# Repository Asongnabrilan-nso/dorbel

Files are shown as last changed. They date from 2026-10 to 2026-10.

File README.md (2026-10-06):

# Dorbel: an AI smart doorbell on the Arduino UNO Q

<p align="center">
  <a href="https://youtu.be/h4dxzuG-TlU">
    Watch the Dorbel demo video on YouTube
  </a>
  <br>
  <em>▶ Click to watch the demo video on YouTube</em>
</p>

<p align="center">
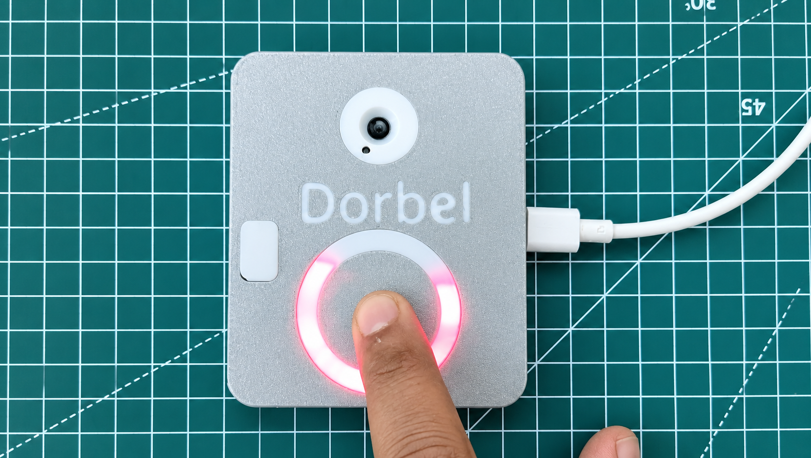
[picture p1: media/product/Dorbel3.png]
Dorbel with the light ring glowing while the button is pressed
  
</p>

Dorbel is a private video doorbell that does all of its thinking at the edge. When a visitor presses the button, the door chimes and your phone gets a Telegram photo. A dashboard on your local network shows live video and lets you talk to the visitor. An AI model running on the board also spots people at the door, even when they don't ring.

| | |
|---|---|
| **Brain** | Arduino UNO Q (4 GB), running an Arduino App Lab app |
| **Camera, mic and speaker** | Seeed XIAO ESP32S3 Sense with a MAX98357A amplifier |
| **AI** | App Lab Video Object Detection brick with the YoloX nano model |
| **Alerts** | App Lab Telegram Bot brick |
| **Privacy** | Video and audio stay on your Wi-Fi. Only the alerts leave the house. |

The build is split into nine steps. Each step ends with a check, so make sure it passes before you move on. Pin tables, the I²C protocol, subsystem tests and the full troubleshooting list live in [docs/REFERENCE.md](docs/REFERENCE.md).

## Contents

1. [How it works](#1-how-it-works)
2. [Gather the parts](#2-gather-the-parts)
3. [Print the enclosure](#3-print-the-enclosure)
4. [Flash the XIAO](#4-flash-the-xiao)
5. [Wire the UNO Q](#5-wire-the-uno-q)
6. [Create the App Lab app](#6-create-the-app-lab-app)
7. [Add AI person detection](#7-add-ai-person-detection)
8. [Add the Telegram Bot brick](#8-add-the-telegram-bot-brick)
9. [Assemble, mount and test](#9-assemble-mount-and-test)
10. [Troubleshooting](#troubleshooting)
11. [How AI was used in this project](#how-ai-was-used-in-this-project)

<br>

## 1. How it works

<p align="center">
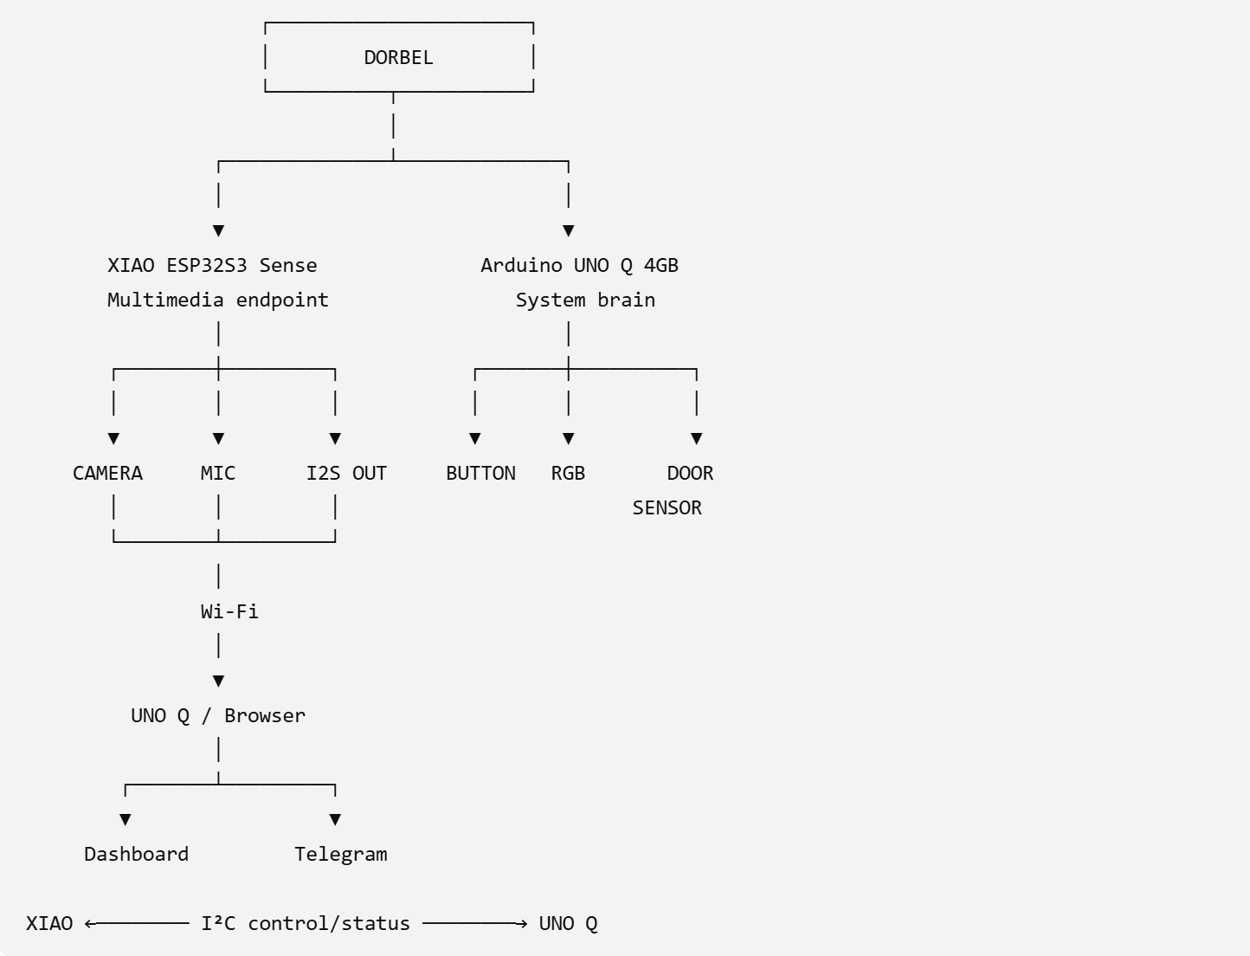
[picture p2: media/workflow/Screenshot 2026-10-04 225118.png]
Dorbel block diagram
  
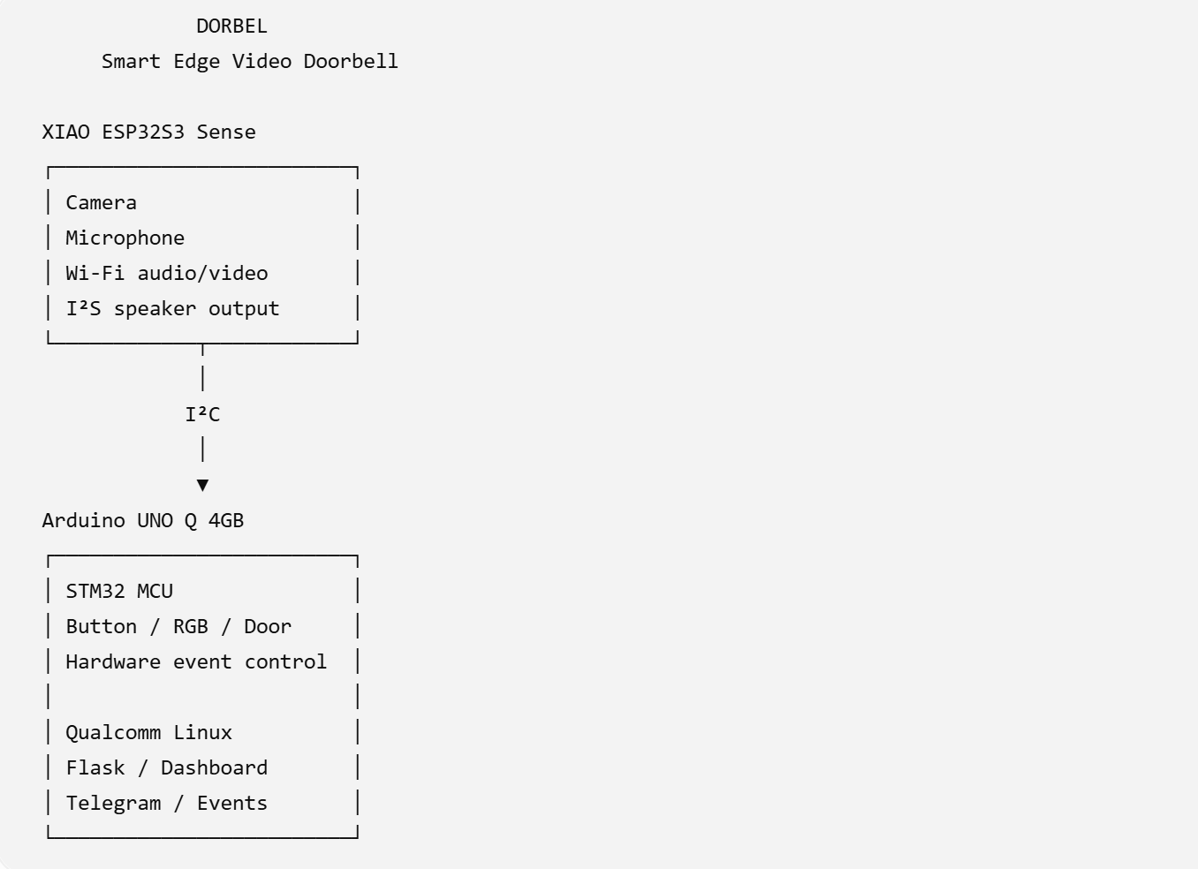
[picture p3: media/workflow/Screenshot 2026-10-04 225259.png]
What each board is responsible for
  
</p>

The UNO Q has two processors, and an App Lab app uses both of them.

| UNO Q side | What runs there | What Dorbel uses it for |
|---|---|---|
| **MCU** (STM32U585) | The app's **sketch** in `sketch/` | Button, RGB LED, I²C link to the XIAO |
| **MPU** (Qualcomm QRB2210, Debian Linux) | The app's **Python** code in `python/` and its **bricks** | Dashboard, AI, Telegram |

The two sides talk through the **Bridge**. The sketch publishes functions with `Bridge.provide_safe()` and Python calls them with `Bridge.call()`.

```
RING    button > UNO Q MCU > I²C > XIAO > chime on the door speaker
                     |
                     +> Bridge > Python > Telegram Bot brick > photo alert on your phone

VIDEO   XIAO camera > Wi-Fi > CameraHub (Python) +> dashboard (any number of viewers)
                                                 +> Video Object Detection brick (YoloX nano)
                                                       +> "person" > dashboard + phone alert

AUDIO   browser mic <> UNO Q dashboard <> Wi-Fi <> XIAO mic and speaker (push to talk)
```

One rule keeps the design simple: **I²C carries control and status, Wi-Fi carries video and audio.** The XIAO also reports its IP address over I²C, so the UNO Q finds the camera without any setup.

<br>

## 2. Gather the parts

<p align="center">
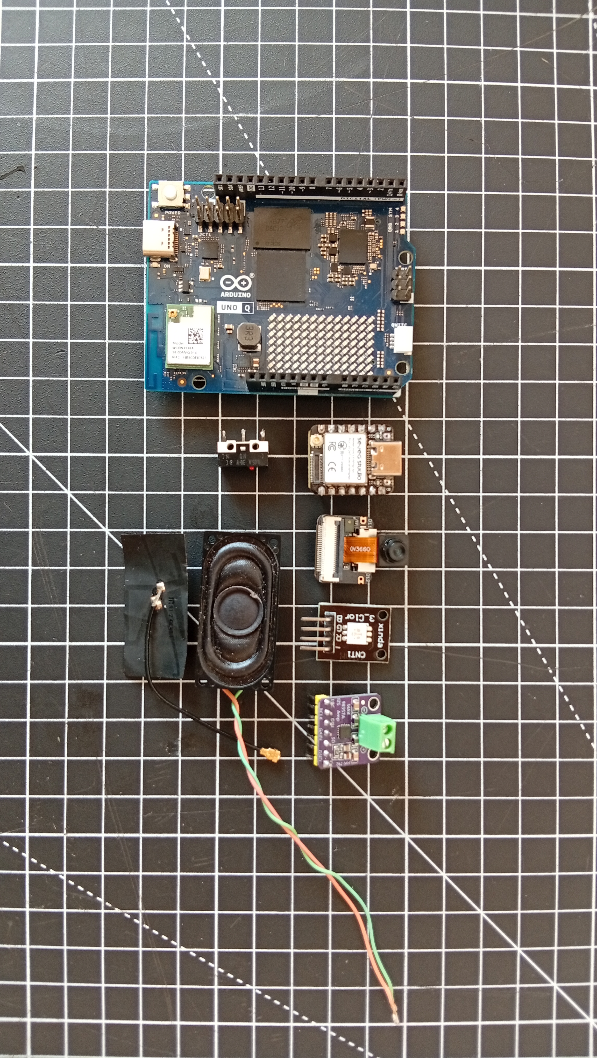
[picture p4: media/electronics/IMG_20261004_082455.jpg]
All Dorbel electronics laid out
  
</p>

| Qty | Part | Role |
|:---:|---|---|
| 1 | Arduino UNO Q (4 GB) | System brain, runs the App Lab app |
| 1 | Seeed XIAO ESP32S3 **Sense** with the camera and mic board | Camera, microphone, Wi-Fi media |
| 1 | MAX98357A I2S amplifier | Drives the speaker |
| 1 | 8 Ω, 2 W speaker | Chime and the homeowner's voice |
| 1 | Momentary push button | The doorbell |
| 1 | RGB LED (common cathode) with 3 × 220 Ω resistors, or an RGB module | Status light |
| 2 | 4.7 kΩ resistors | I²C pull-ups |
| | Jumper wires, 2 USB-C data cables, PLA filament | |
| | 2.4 GHz Wi-Fi with internet, a phone with Telegram | |

<p align="center">
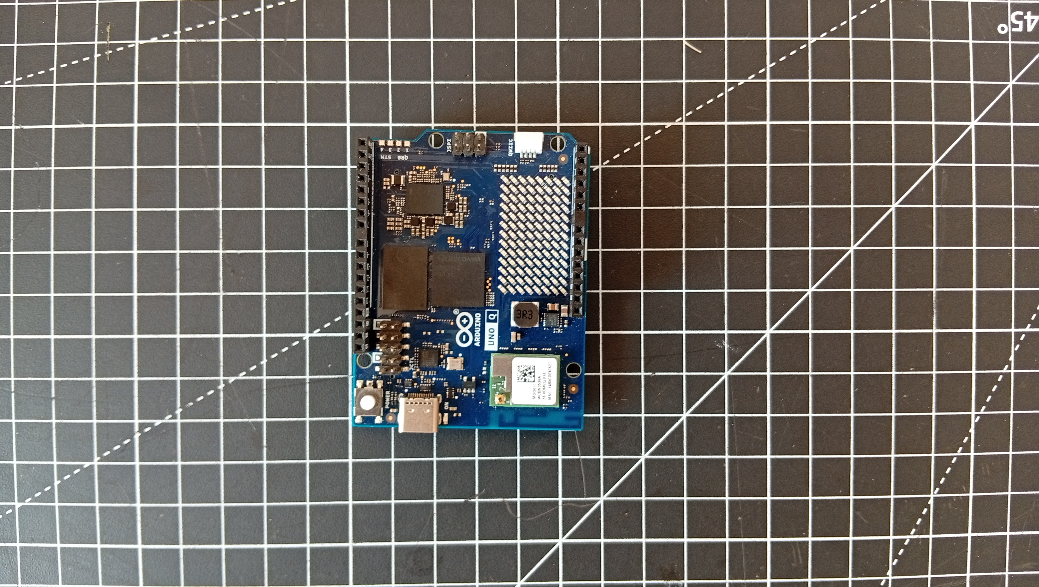
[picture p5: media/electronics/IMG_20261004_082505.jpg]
Arduino UNO Q
  
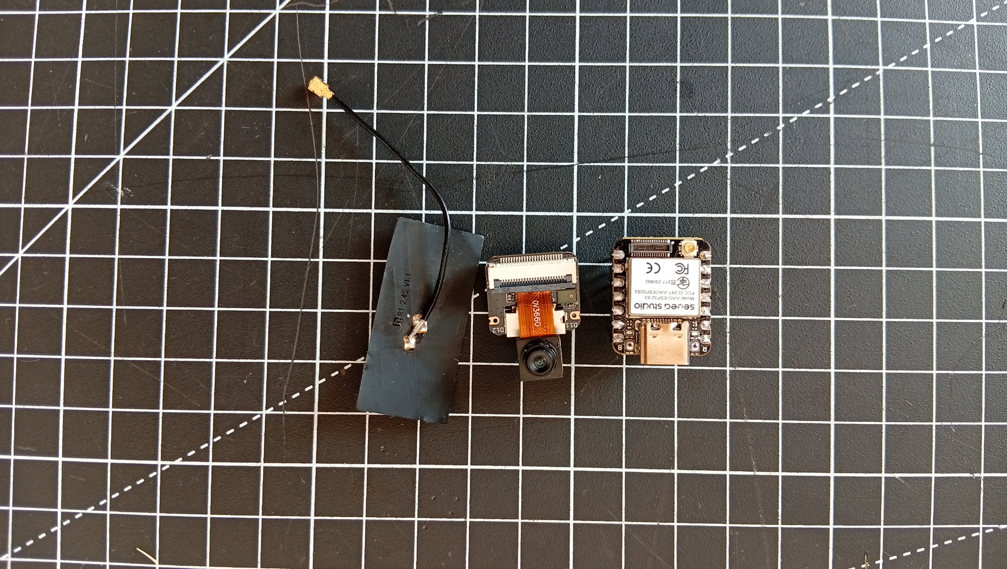
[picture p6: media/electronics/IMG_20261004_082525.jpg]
XIAO ESP32S3 Sense with camera and antenna
  
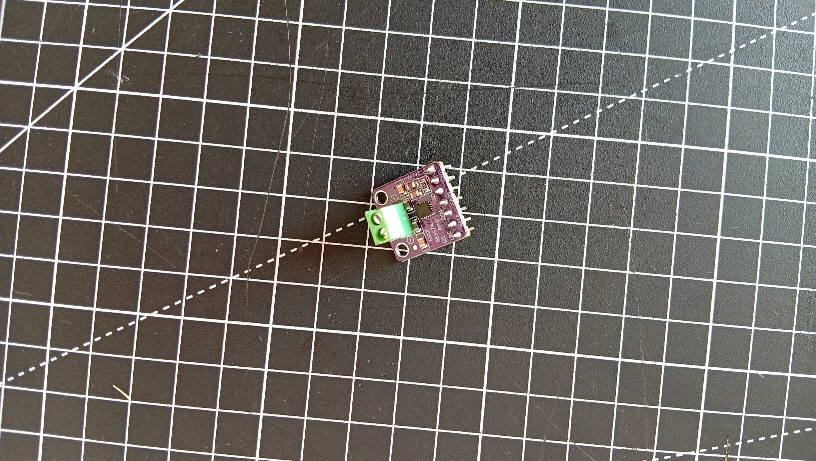
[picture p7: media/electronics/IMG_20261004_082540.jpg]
MAX98357A amplifier
  
</p>
<p align="center">
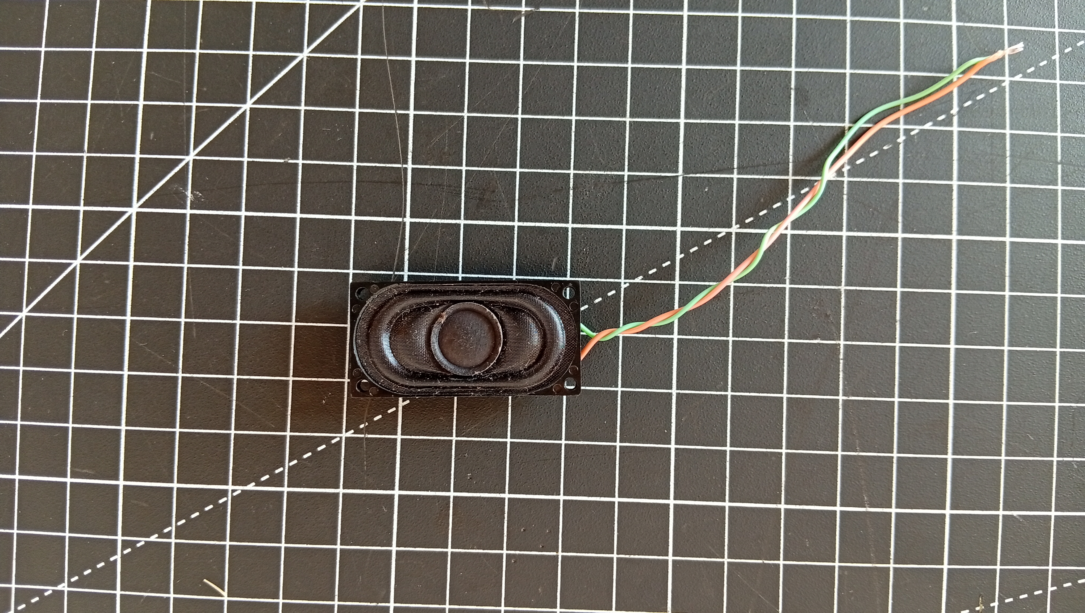
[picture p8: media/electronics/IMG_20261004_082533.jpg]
8 ohm speaker
  
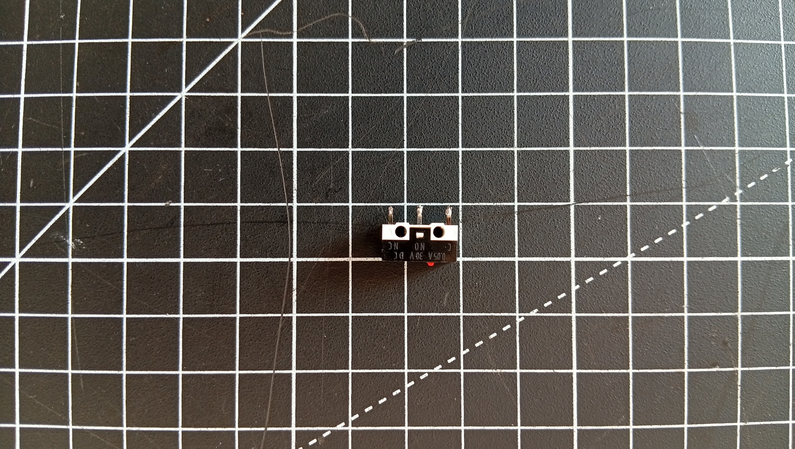
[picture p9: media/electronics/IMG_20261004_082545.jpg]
Push button
  
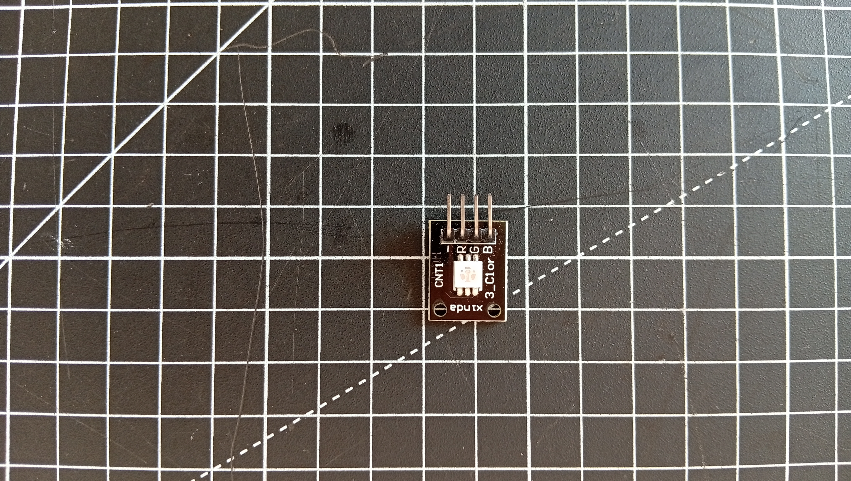
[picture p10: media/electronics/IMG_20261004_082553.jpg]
RGB LED module
  
</p>
<p align="center"><sub>UNO Q · XIAO ESP32S3 Sense · MAX98357A · speaker · push button · RGB LED</sub></p>

**Software you need:** [Arduino App Lab](https://www.arduino.cc/en/software/) (already on the UNO Q), [PlatformIO](https://platformio.org/) on your PC for the XIAO, and Telegram on your phone.

<br>

## 3. Print the enclosure

<p align="center">
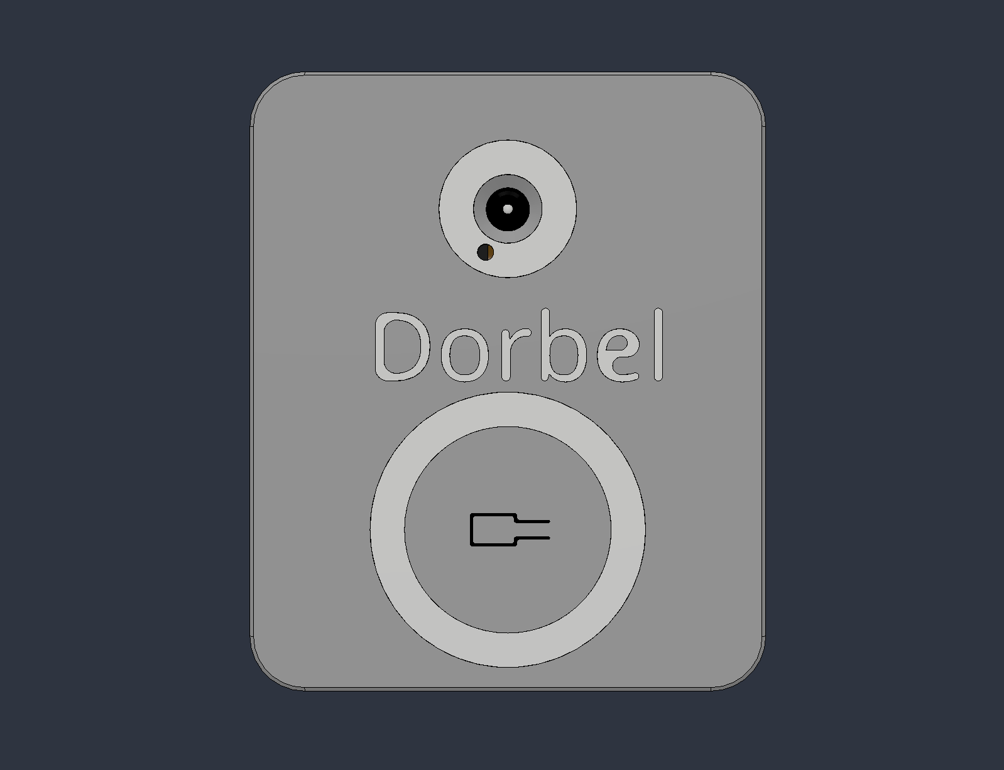
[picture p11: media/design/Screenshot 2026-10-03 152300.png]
Enclosure design in CAD
  
</p>

Print the four parts in the `stl/` folder.

| File | Part |
|---|---|
| `stl/Dorbel-Cover.3mf` | Front cover with the camera hole, light ring button and logo |
| `stl/Dorbel-Base.3mf` | Back shell that holds the electronics |
| `stl/Body2.stl` | Body |
| `stl/wall mount.stl` | Wall plate the doorbell slides onto |

<p align="center">
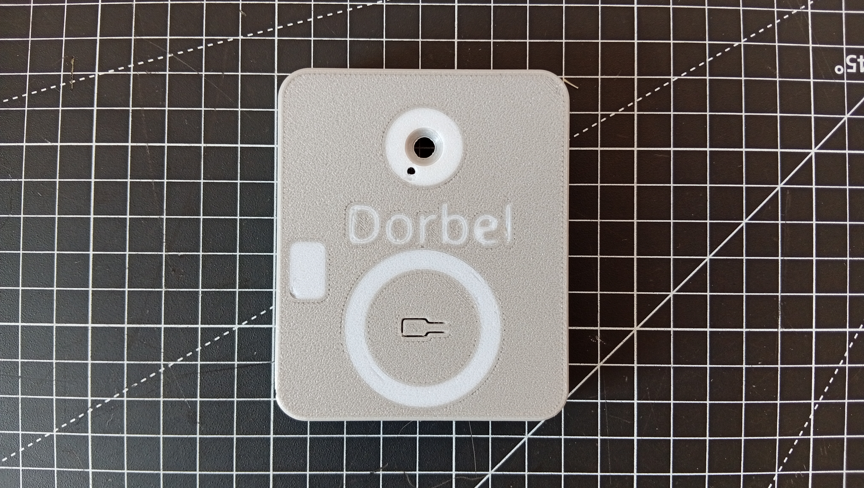
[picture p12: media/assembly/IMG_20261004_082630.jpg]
Printed front cover
  
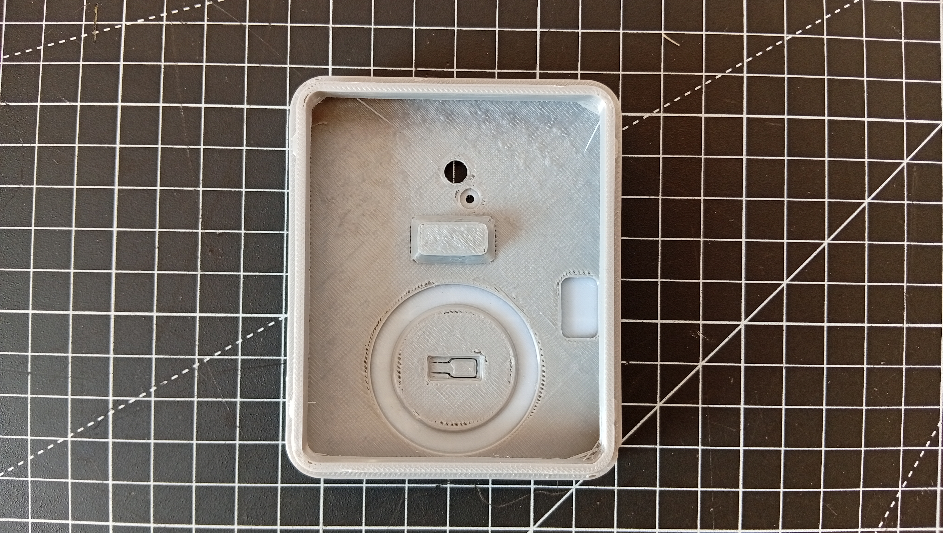
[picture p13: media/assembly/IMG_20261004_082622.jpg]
Inside of the front cover
  
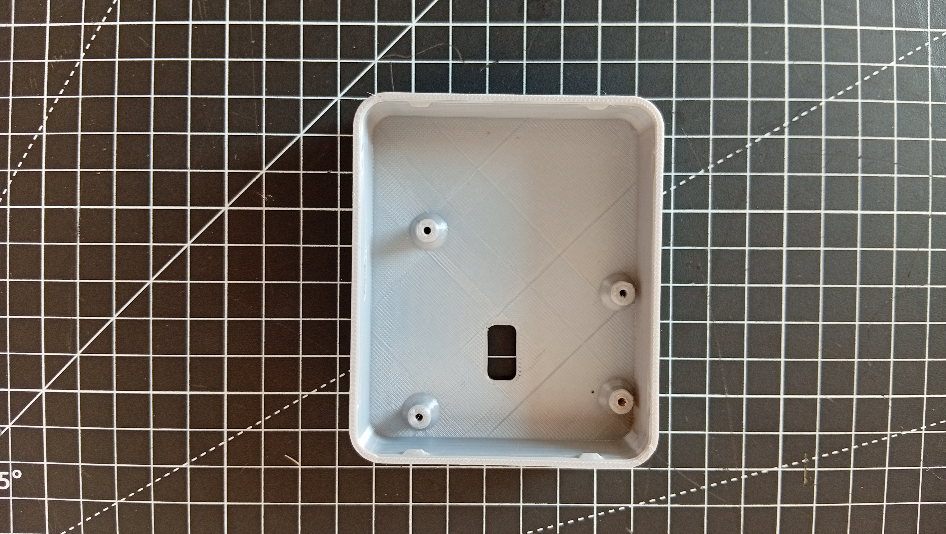
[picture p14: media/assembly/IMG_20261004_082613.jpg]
Inside of the base
  
</p>

> **✅ Check:** the button moves freely inside the ring and the camera lens lines up with the front hole.

<br>

## 4. Flash the XIAO

The XIAO firmware is a PlatformIO project in `xiao/`. Open that folder in PlatformIO, not the repository root.

### 4.1 Wire the speaker

| XIAO pin | MAX98357A pin |
|---|---|
| D8 (GPIO7) | BCLK |
| D3 (GPIO4) | LRC |
| D1 (GPIO2) | DIN |
| 5V | VIN |
| GND | GND |

Connect the speaker between **SPK+ and SPK-**. Never connect SPK- to ground.

### 4.2 Add your Wi-Fi and flash

```bash
cd xiao
cp include/secrets.example.h include/secrets.h   # add your 2.4 GHz SSID and password
pio run -t upload
pio device monitor                               # 115200 baud
```

<p align="center">
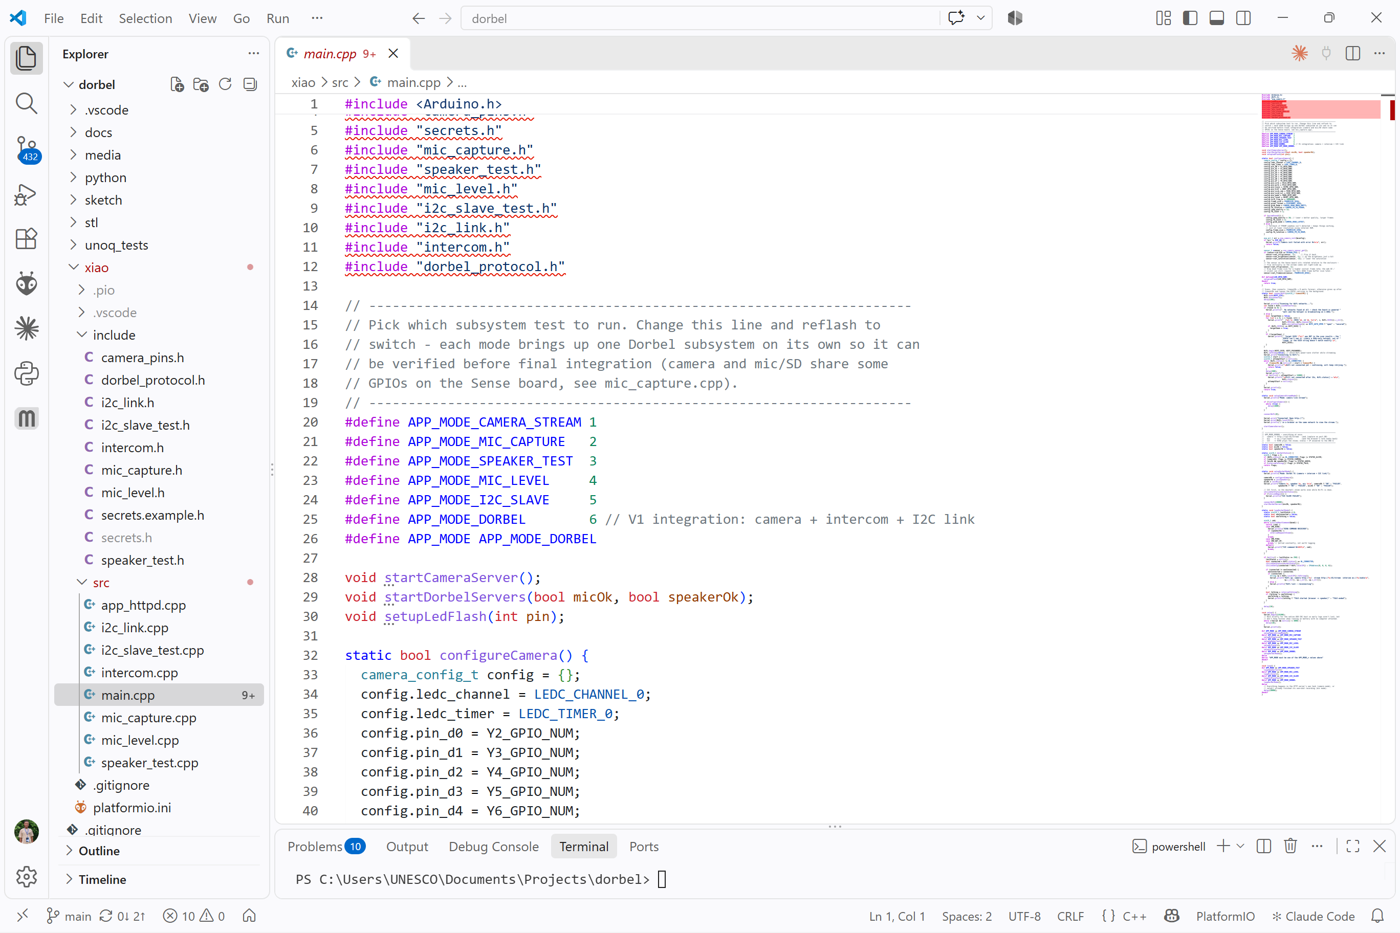
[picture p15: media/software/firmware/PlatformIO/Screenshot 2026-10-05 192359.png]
The xiao project open in VS Code with PlatformIO, showing the APP_MODE options
  
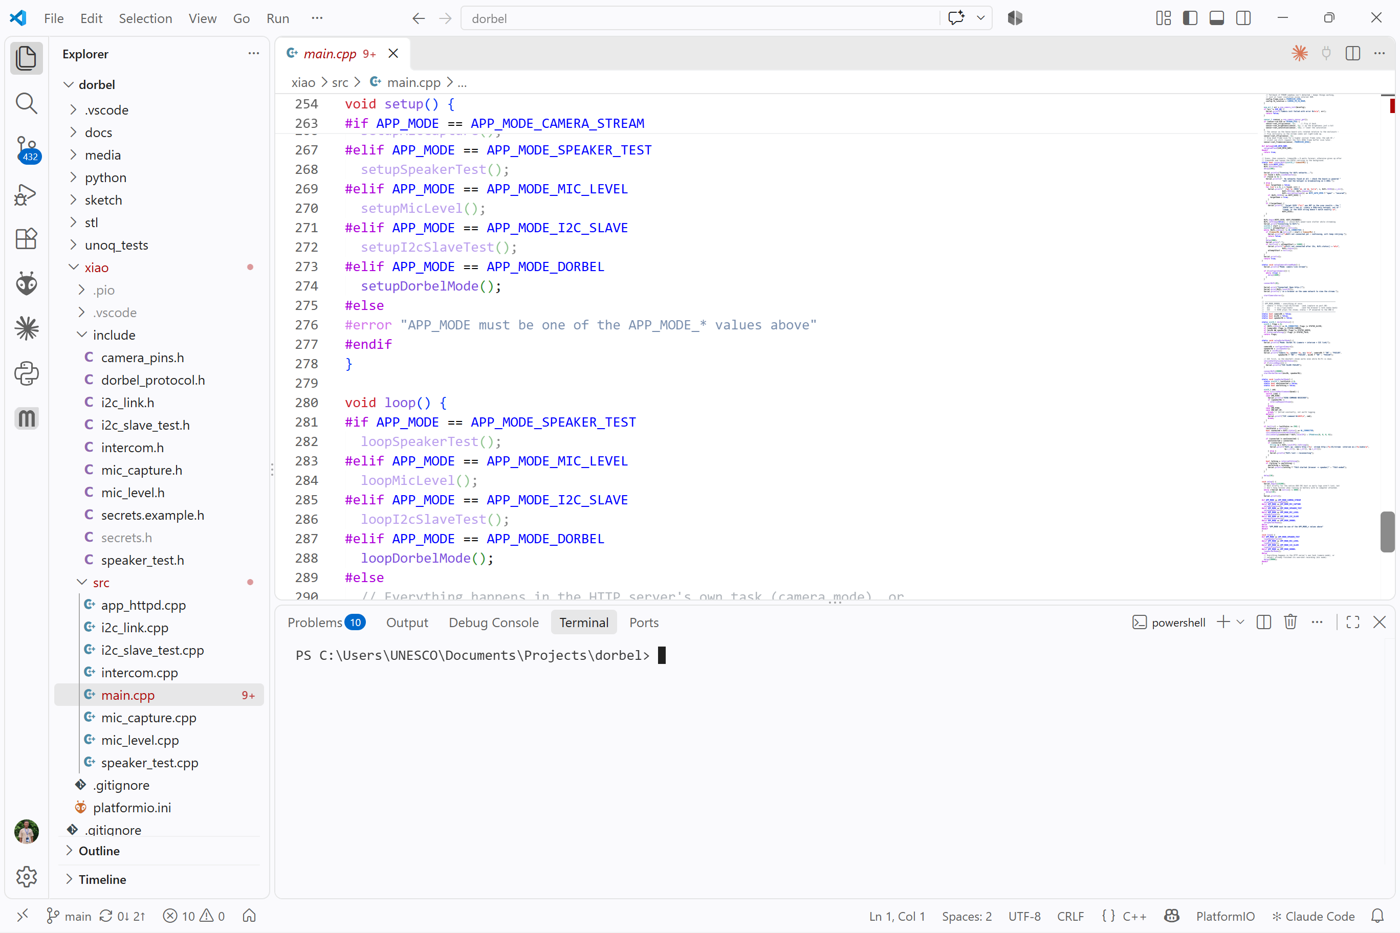
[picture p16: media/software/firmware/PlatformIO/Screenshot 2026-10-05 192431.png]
setup() and loop() picking the code for the selected APP_MODE
  
</p>
<p align="center"><sub>The <code>xiao</code> project in VS Code with PlatformIO. <code>APP_MODE</code> picks what the XIAO runs.</sub></p>

Make sure `xiao/src/main.cpp` has `#define APP_MODE APP_MODE_DORBEL`, which is the default. The other `APP_MODE_*` values test one part at a time (speaker, mic, camera, I²C) and are described in the [reference](docs/REFERENCE.md#build-order-and-test-status).

<p align="center">
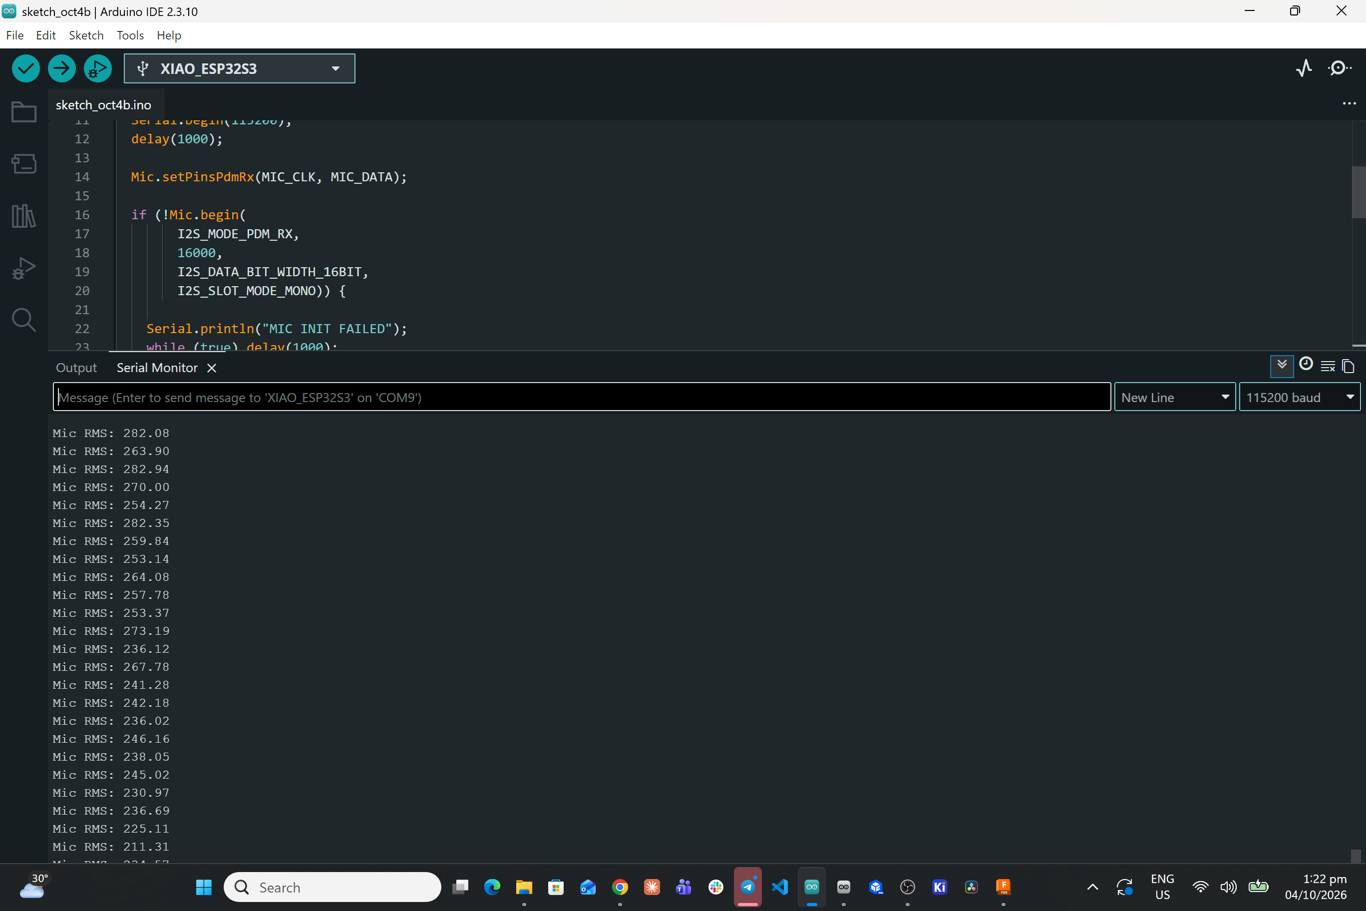
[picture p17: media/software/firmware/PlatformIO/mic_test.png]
PlatformIO serial monitor during the mic test
  
</p>
<p align="center"><sub>The mic level test, one of the single subsystem modes</sub></p>

> **✅ Check:** the serial log ends with a line like
> `WiFi up: camera http://192.168.x.y/  stream http://192.168.x.y:81/stream  intercom ws://192.168.x.y/audio`.
> Open `http://192.168.x.y/` on your PC to see the camera, then close the tab. The XIAO only streams to one client, and that slot belongs to the UNO Q.

<p align="center">
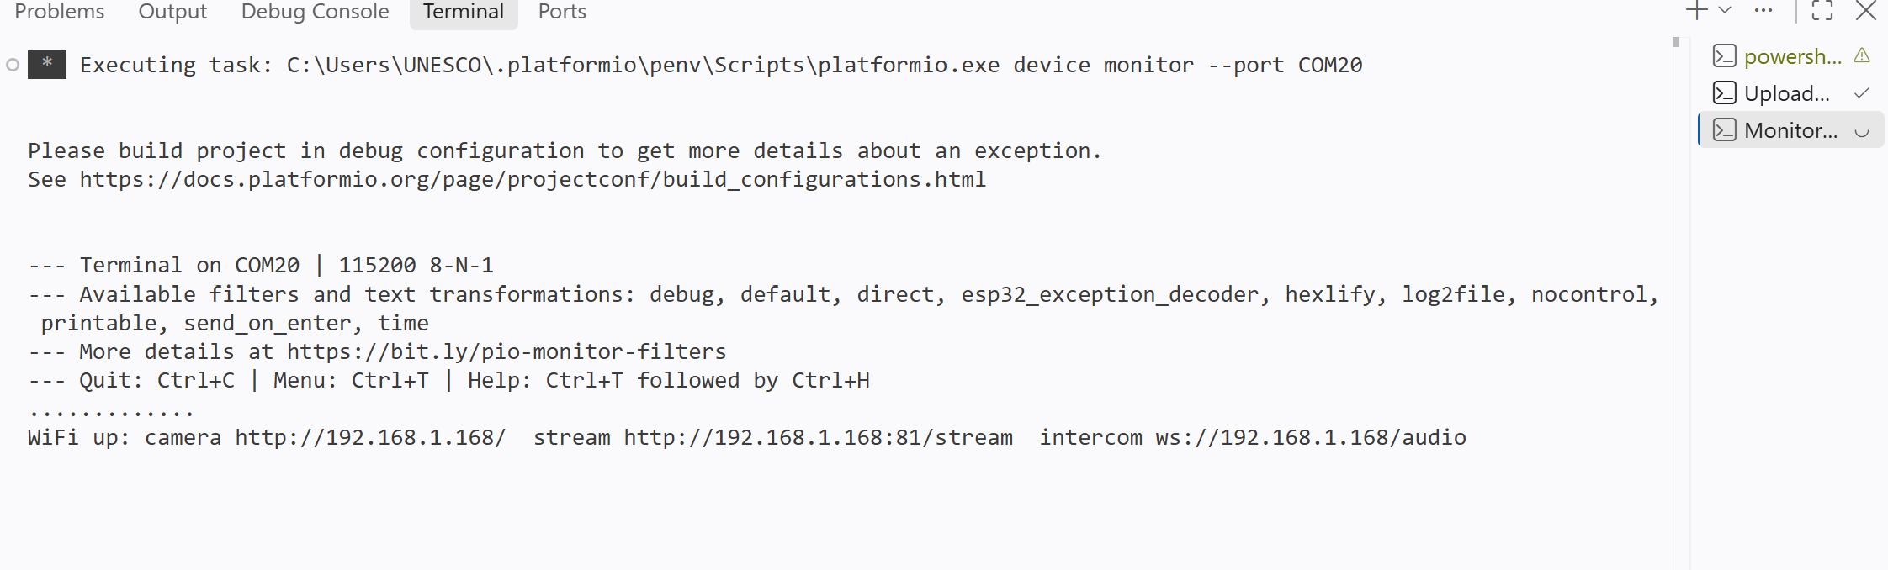
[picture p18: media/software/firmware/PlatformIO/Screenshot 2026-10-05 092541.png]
Serial monitor showing the XIAO connected to Wi-Fi with its camera, stream and intercom addresses
  
</p>

> **⚠️ Important:** the XIAO and the UNO Q must be on the **same 2.4 GHz network**. If they aren't, video, talk and photos all stop working.

<br>

## 5. Wire the UNO Q

| UNO Q pin | Connects to | Notes |
|---|---|---|
| D2 | Push button, other leg to GND | Uses `INPUT_PULLUP` |
| D3, D5, D6 | RGB red, green, blue through 220 Ω | Common cathode to GND |
| **A4** (SDA) | XIAO D4 | `Wire2` in the sketch, not the D20/D21 header |
| **A5** (SCL) | XIAO D5 | |
| GND | XIAO GND | The boards must share ground |
| 3.3 V | 4.7 kΩ to SDA and 4.7 kΩ to SCL | One pair of pull-ups for the whole bus |

The UNO Q is the I²C master and the XIAO is a slave at address `0x08`.

<p align="center">
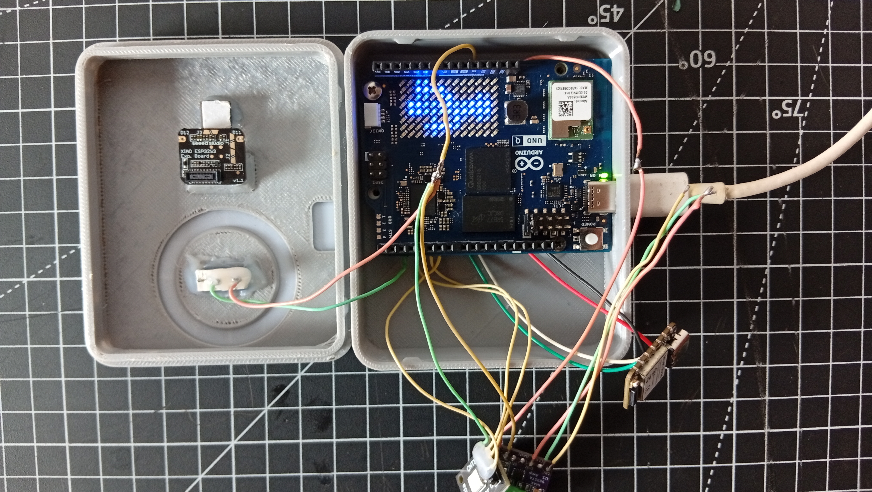
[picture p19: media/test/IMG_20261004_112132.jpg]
UNO Q and XIAO wired on the bench
  
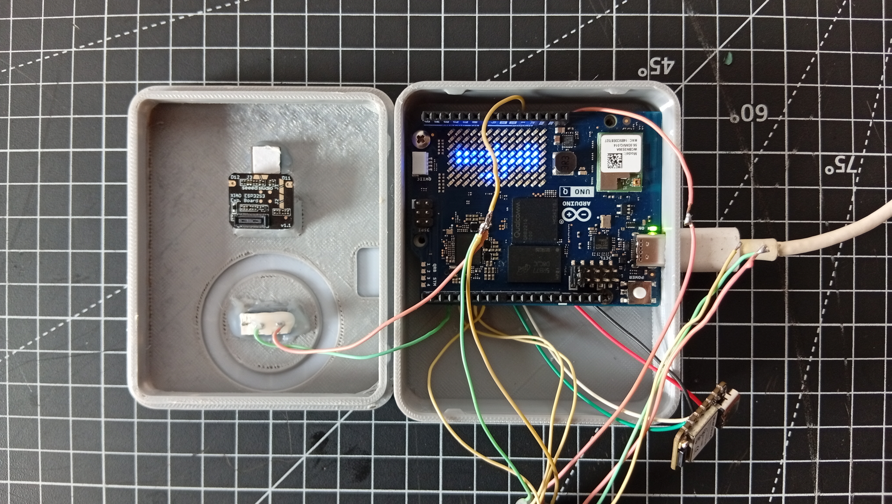
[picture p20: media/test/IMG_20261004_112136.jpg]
Bench wiring from another angle
  
</p>

> **✅ Check:** once the app runs in step 6, the RGB LED shows the link state.

<p align="center">
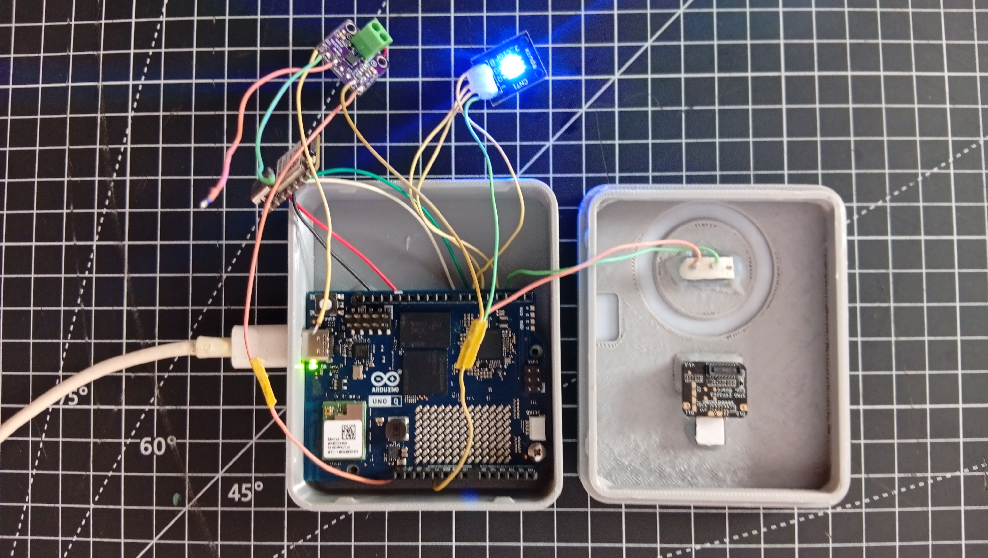
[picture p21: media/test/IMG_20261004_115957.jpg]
Blue LED: XIAO not answering
  
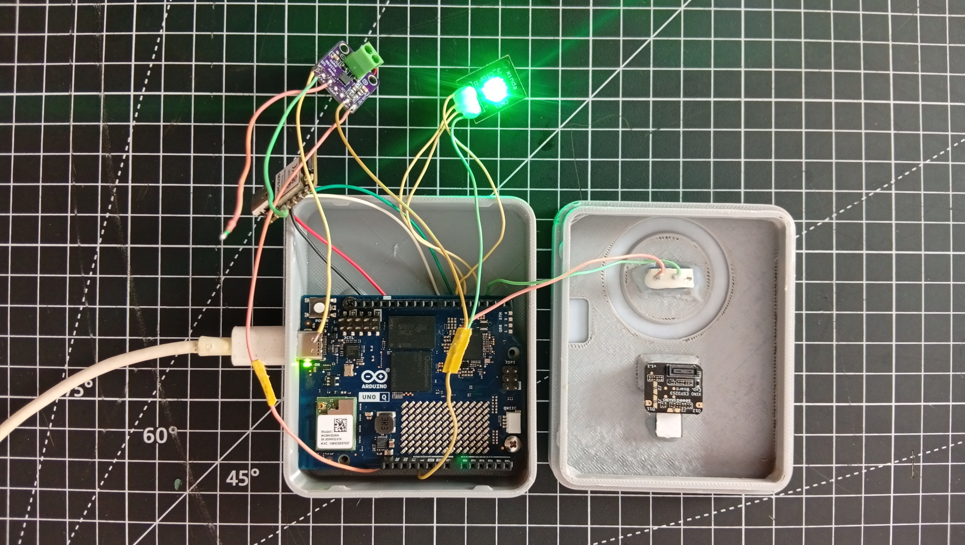
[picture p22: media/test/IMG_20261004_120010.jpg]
Green LED: idle and linked
  
</p>
<p align="center"><sub>Blue means the XIAO is not answering on I²C · Green means idle and linked · Red means a ring was just sent</sub></p>

<br>

## 6. Create the App Lab app

In App Lab, an **app** is a folder inside `~/ArduinoApps/` with this layout:

```
app.yaml      name, icon, published ports and the bricks the app uses
sketch/       code for the MCU
python/       code for Linux, starting from main.py
```

Open App Lab on your PC. If it says **No boards found**, connect the UNO Q over USB or put it on the same network as your PC. Once the board shows up, App Lab opens on its **Apps** page, with **Examples** and **Inspirations** under *Learn and Explore* if you want to see how other apps are built.

<p align="center">
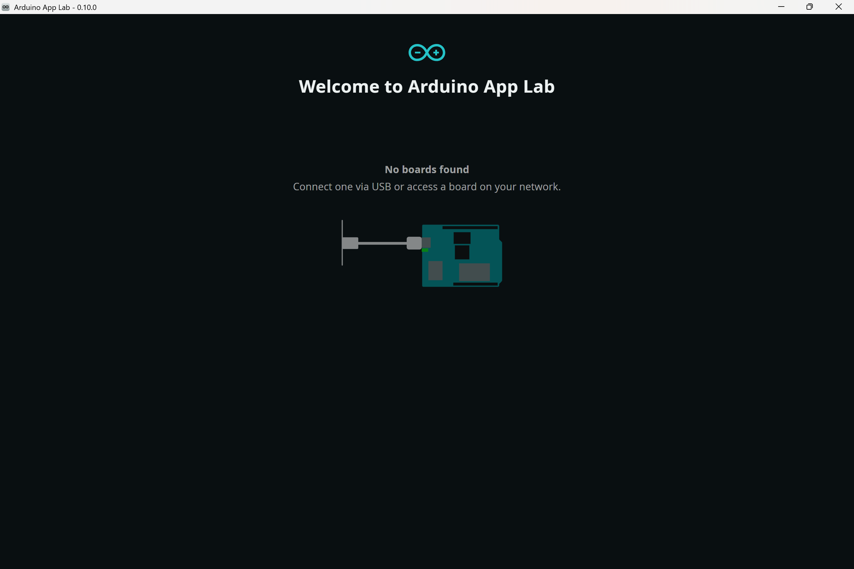
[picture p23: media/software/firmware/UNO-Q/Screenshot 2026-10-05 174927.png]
App Lab start screen waiting for a board
  
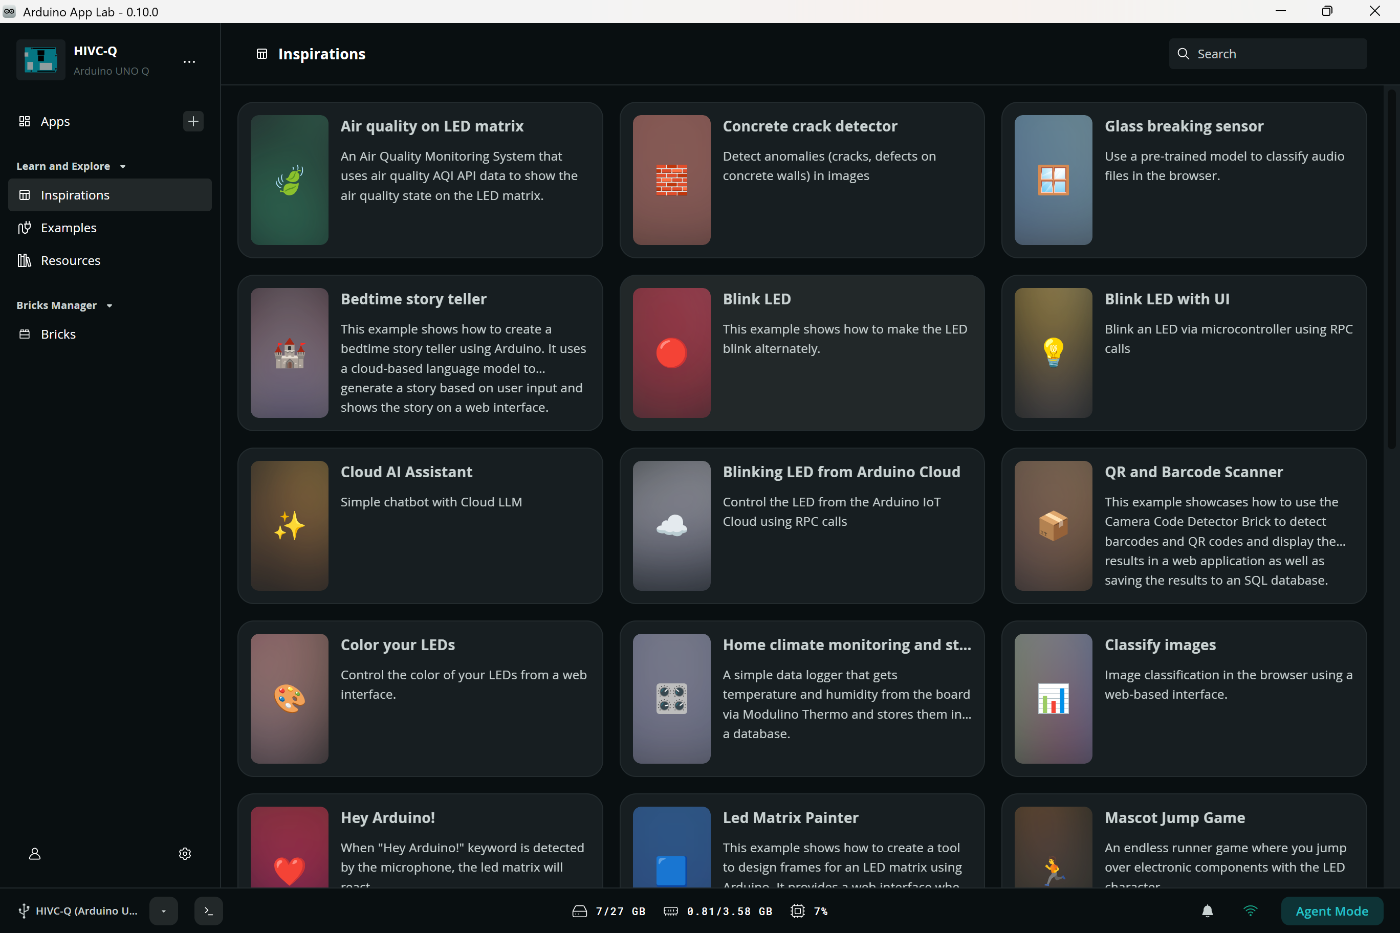
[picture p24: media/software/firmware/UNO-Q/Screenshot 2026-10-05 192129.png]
App Lab Inspirations page with example apps
  
</p>

This repository is that folder. Open a terminal on the UNO Q (the board's desktop, `ssh arduino@<board>.local` or `adb shell`) and run:

```bash
cd ~/ArduinoApps
git clone https://github.com/Asongnabrilan-nso/dorbel.git dorbel
cd dorbel/python
cp dorbel_config_example.py dorbel_config.py      # local settings, kept out of git
hostname -I                                       # shows the UNO Q's IP address
```

In `python/dorbel_config.py`, set the dashboard address that the alerts will link to:

```python
DASHBOARD_URL = "https://192.168.x.z:8443/"      # the UNO Q IP from hostname -I
```

Go back to App Lab. **Dorbel 🔔** now shows on the **Apps** page. Open it to see the bricks, the files and the code, then click **Run**.

<p align="center">
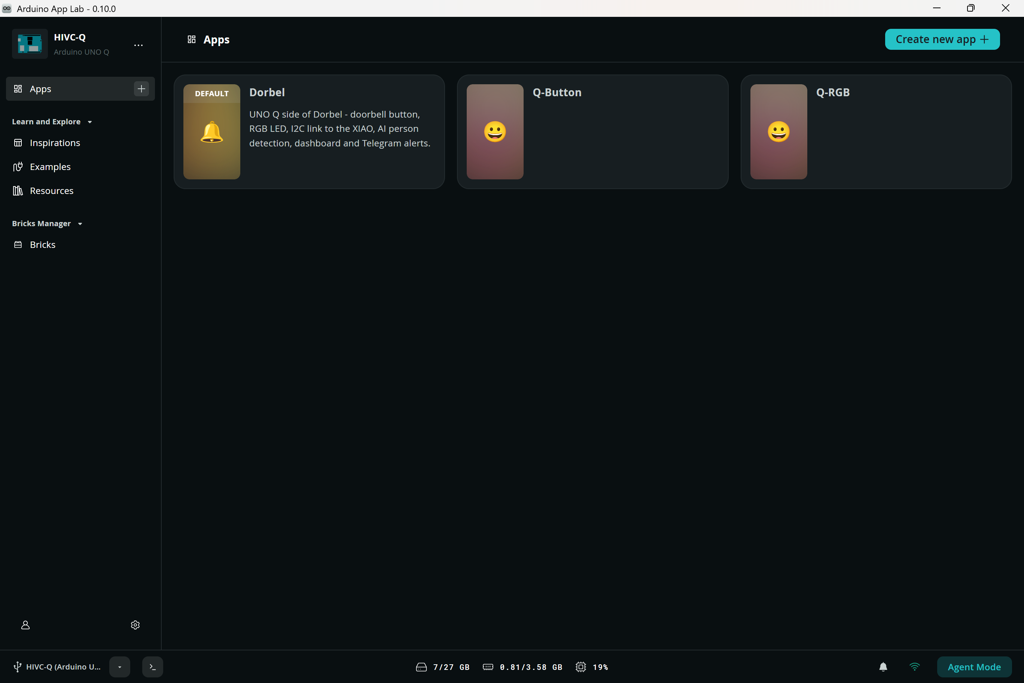
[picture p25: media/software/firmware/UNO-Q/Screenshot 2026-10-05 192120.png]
App Lab Apps page with the Dorbel app
  
</p>

When you click **Run**, App Lab will:

1. compile the sketch and flash it to the MCU (progress shows in the **App launch** tab),
2. start the app's bricks,
3. start `python/main.py` and show its output in the **Python** tab.

<p align="center">
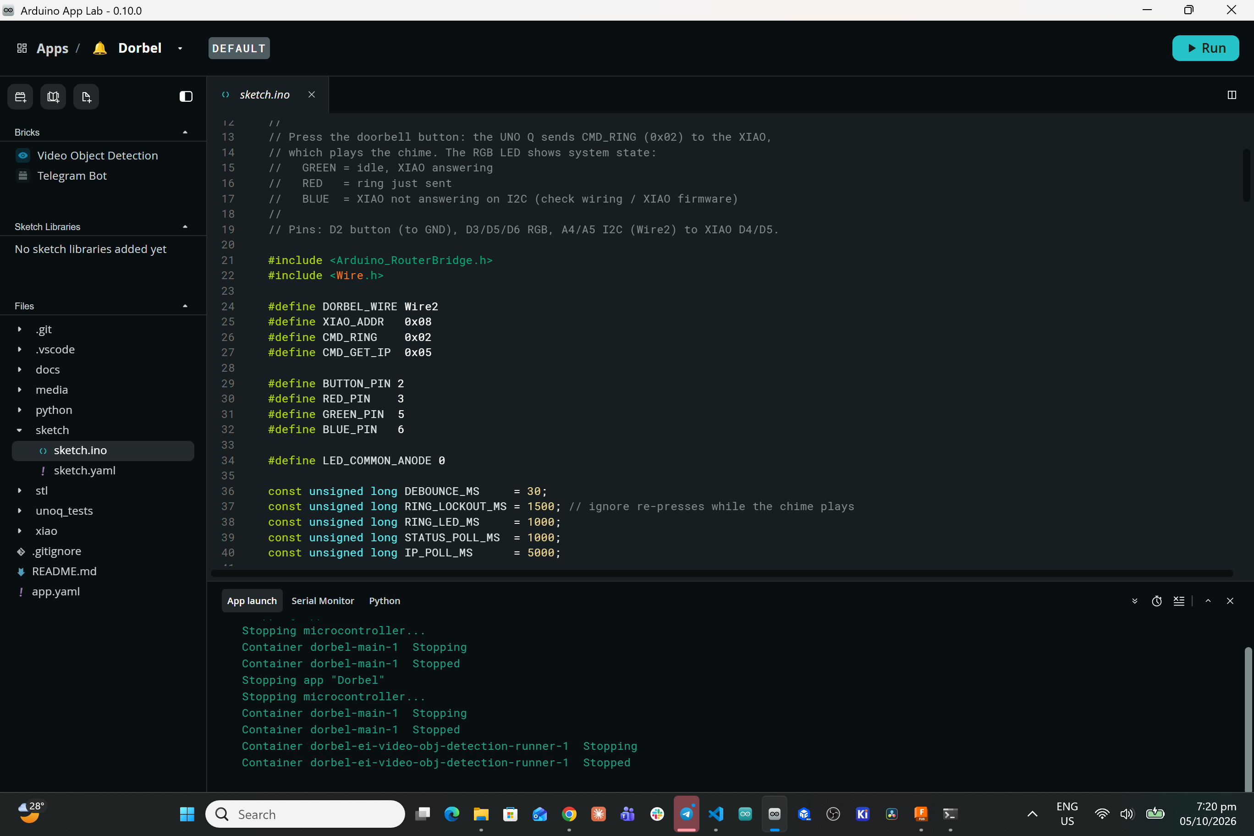
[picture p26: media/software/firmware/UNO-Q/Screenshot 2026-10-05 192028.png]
Dorbel sketch open in App Lab with the bricks listed
  
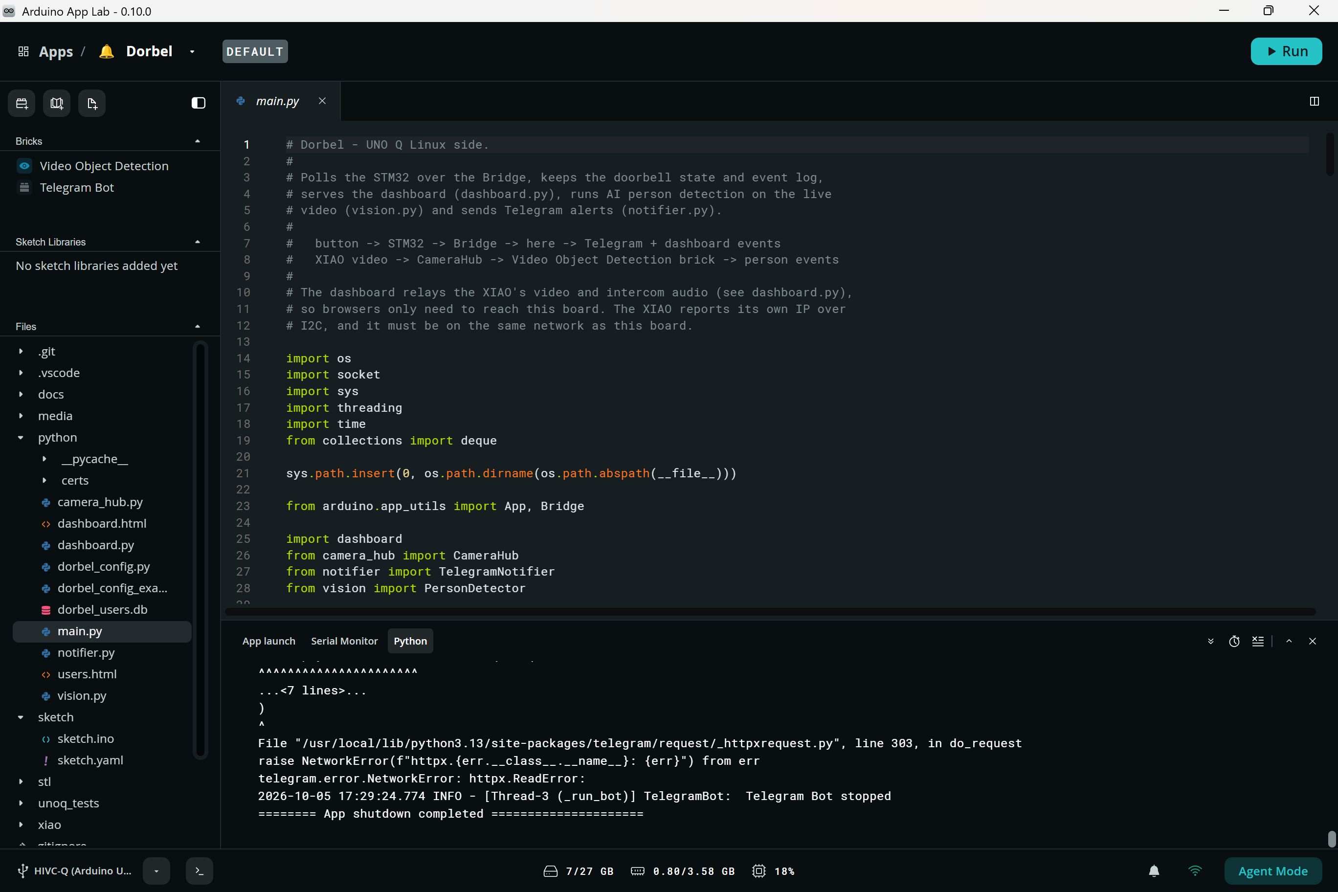
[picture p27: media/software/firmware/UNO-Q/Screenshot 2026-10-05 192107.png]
Dorbel main.py open in App Lab with the Python tab
  
</p>
<p align="center"><sub>Left: the sketch, with the app's bricks listed at the top. Right: <code>main.py</code> and the Python output.</sub></p>

### What the sketch does

`sketch/sketch.ino` debounces the button, sends `RING` to the XIAO over I²C, drives the LED and publishes four functions over the Bridge.

| Bridge function | Returns |
|---|---|
| `get_doorbell_state` | `1` if the button was pressed since the last clear |
| `clear_event` | Clears the press |
| `get_xiao_status` | XIAO status bits, or `-1` if it isn't answering |
| `get_xiao_ip` | The XIAO's IP address packed into a number |

`python/main.py` calls these four times a second and handles everything else.

> **✅ Check:** the **Python** tab shows these lines, and pressing the button plays the chime at the door.
>
> ```
> Dorbel dashboard: https://192.168.x.z:8443/
> [event] System started
> [event] MCU connected
> [event] XIAO online
> [event] Camera at 192.168.x.y
> [event] Camera reachable at 192.168.x.y
> ```

### Open the dashboard

Go to `https://<unoq-ip>:8443/` and accept the self-signed certificate the first time. You'll see live video, the system status and the push to talk button.

<p align="center">
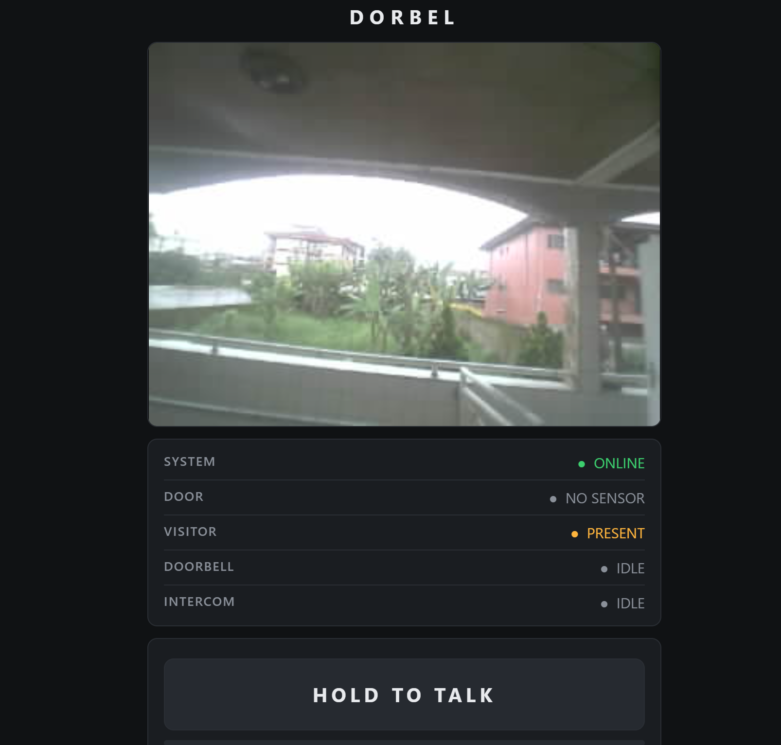
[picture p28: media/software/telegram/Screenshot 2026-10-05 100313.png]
Dashboard with live video and status
  
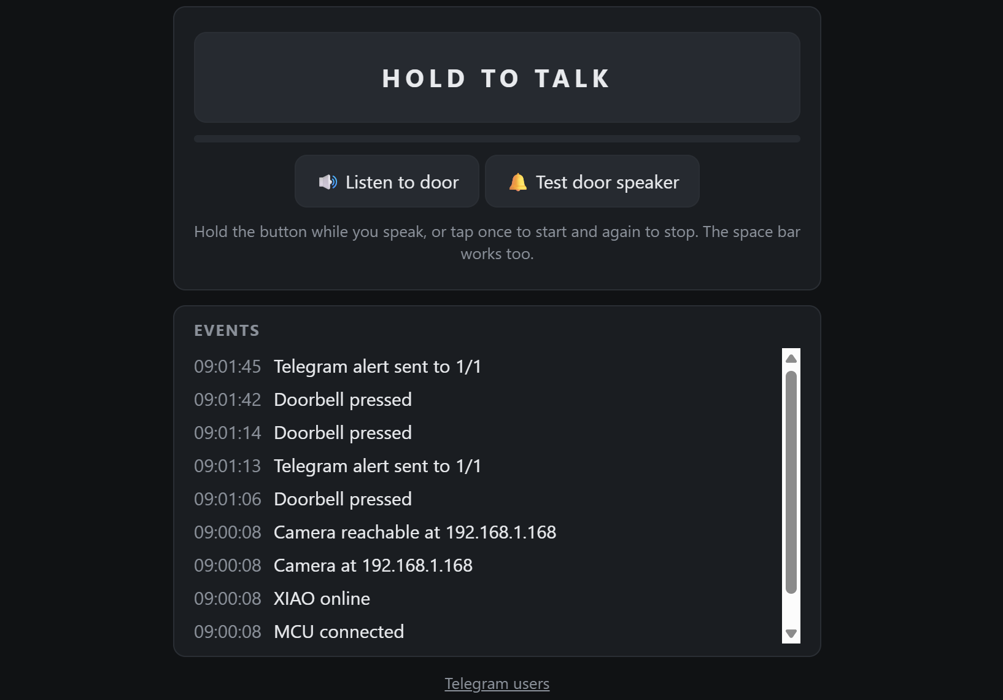
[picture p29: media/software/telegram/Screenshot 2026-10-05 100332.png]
Dashboard with hold to talk and the event log
  
</p>

The dashboard uses HTTPS because browsers only allow the microphone on secure pages. **Hold to talk** sends your voice to the door speaker and **Listen to door** plays the XIAO's microphone.

<br>

## 7. Add AI person detection

This step adds the **Video Object Detection** brick. It runs the YoloX nano model, which knows 80 everyday object classes including `person`, directly on the UNO Q. Camera frames never leave the board.

### 7.1 Add the brick

You can read about every brick in App Lab under **Bricks Manager > Bricks**. The **AI models** tab of Video Object Detection lists the models it can run.

<p align="center">
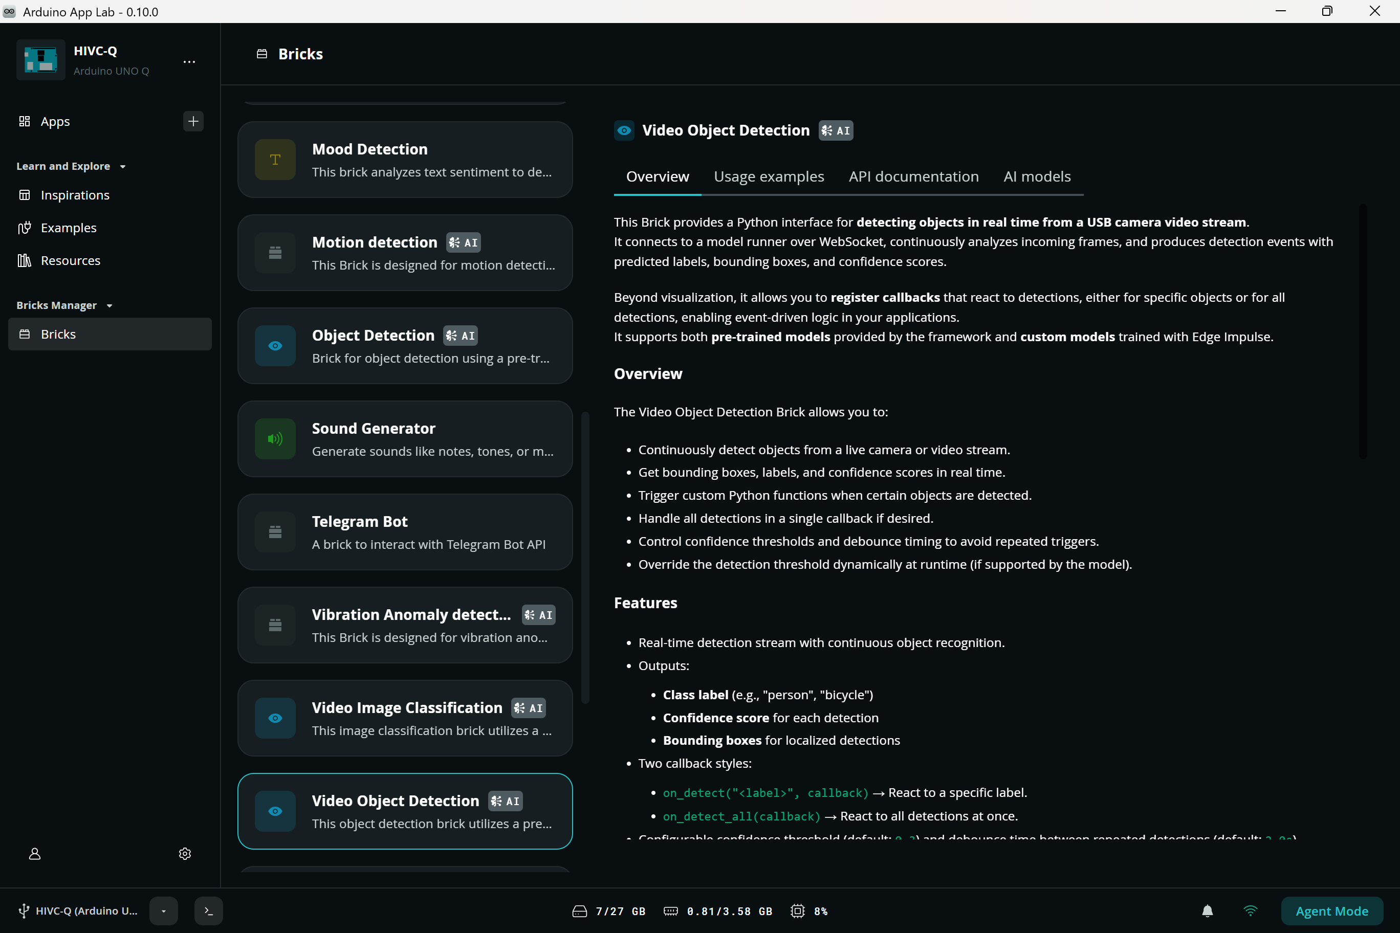
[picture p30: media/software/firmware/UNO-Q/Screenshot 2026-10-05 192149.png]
Video Object Detection brick page in App Lab's Bricks Manager
  
</p>

Add **Video Object Detection** to the app from the app's **Bricks** panel and keep the model *General purpose object detection, YoloX nano*. In `app.yaml` it looks like this:

```yaml
bricks:
- arduino:video_object_detection:
    model: yolox-object-detection
    devices:
    - remote_camera_0
```

The brick normally expects a USB camera. `remote_camera_0` tells App Lab the camera comes over the network instead, the same way the brick's smartphone camera example works.

### 7.2 Feed it the XIAO camera

The XIAO only serves one video stream at a time, so the dashboard and the AI can't each open their own. `python/camera_hub.py` reads the stream once and shares it.

- `CameraHub` keeps the newest frame and sends it to every dashboard viewer.
- `XiaoCamera` is an App Lab `BaseCamera` that gives the brick those same frames, as if a camera were plugged into the board.

```python
camera = CameraHub(current_xiao_ip)
detector = VideoObjectDetection(camera=XiaoCamera(camera), confidence=0.5, camera_preview=True)
```

### 7.3 React to people

`python/vision.py` registers an `on_detect_all()` callback, keeps only the `person` results, draws the boxes with App Lab's `draw_bounding_boxes()` helper and reacts once each time someone arrives.

```python
def on_detect_all(detections: dict, frame: bytes = None):
    people = detections.get("person", [])   # [{"confidence": 0.87, "bounding_box_xyxy": (...)}]
```

When a person arrives, Dorbel logs `AI: person detected at the door`, sets VISITOR to PRESENT and sends a Telegram photo (set up in step 8).

### 7.4 Tune it

These settings live in `python/dorbel_config.py`:

```python
PERSON_DETECTION = True        # turn the AI on or off
PERSON_CONFIDENCE = 0.5        # raise it if shadows count as people, lower it if people are missed
PERSON_ALERTS = True           # send a Telegram photo when a person arrives
PERSON_ALERT_INTERVAL_S = 120  # at most one person alert every 2 minutes
```

<p align="center">
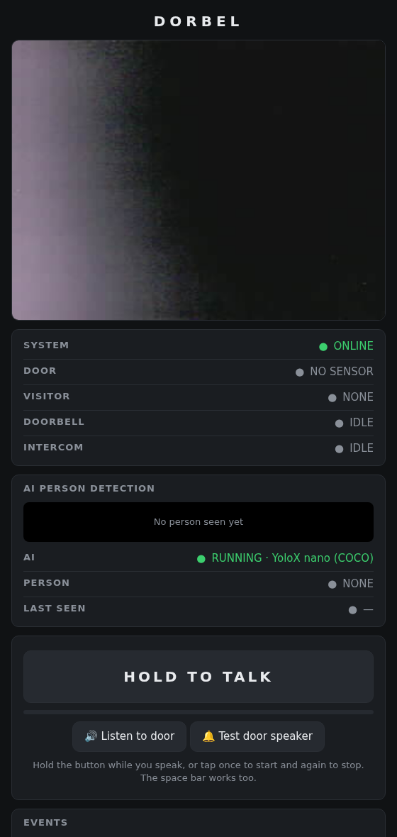
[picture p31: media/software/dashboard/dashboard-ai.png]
Dashboard with the AI person detection panel
  
</p>

> **✅ Check:** run the app again. The **AI PERSON DETECTION** panel shows `RUNNING · YoloX nano (COCO)`. Step in front of the camera and you should see:
>
> - a `👤 PERSON 87%` badge on the live video,
> - your photo with a bounding box, the count and the confidence in the panel,
> - `AI: person detected at the door` in the event log.
>
> To watch the model work on its own, open the brick's preview page at `http://<unoq-ip>:4912`.

<br>

## 8. Add the Telegram Bot brick

### 8.1 Create the bot

In Telegram, open **@BotFather**, send `/newbot`, then choose a name and a username that ends in `bot`. BotFather gives you a **token** such as `123456789:AAH...`. Treat it like a password.

<p align="center">
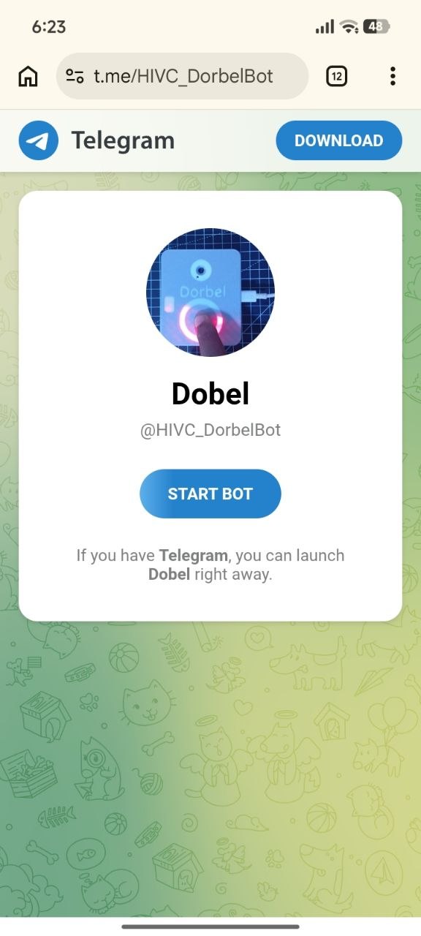
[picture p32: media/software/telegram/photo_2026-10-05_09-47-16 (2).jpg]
The Dorbel bot's start page in Telegram
  
</p>

### 8.2 Add the brick

In App Lab, add **Telegram Bot** from the **Bricks** panel. The brick requires a `TELEGRAM_BOT_TOKEN` variable. This repository is public, so `app.yaml` only holds a placeholder:

```yaml
- arduino:telegram_bot:
    variables:
      TELEGRAM_BOT_TOKEN: set-in-dorbel_config
```

Put your real token in `python/dorbel_config.py`, which git ignores:

```python
TELEGRAM_BOT_TOKEN = "123456789:AAH..."
```

If your copy of the project is private, you can paste the token into the brick's **Brick Configuration** instead.

### 8.3 What the bot does

The bot is set up in `python/notifier.py`:

```python
bot = TelegramBot(token=token)
bot.add_command("start",  register,   "Register for door alerts")
bot.add_command("photo",  send_photo, "Photo from the door camera")
bot.add_command("status", status,     "Dorbel system status")
bot.add_command("help",   help,       "What this bot can do")
```

| When | You get |
|---|---|
| Someone presses the doorbell | `🔔 DORBEL ALERT` with a 1600×1200 photo and the dashboard link |
| The AI sees a person arrive | `👤 Person at the door` with the photo and bounding box |
| You send `/photo` | A fresh full resolution photo |
| You send `/status` | MCU, XIAO, camera and AI status, plus when a person was last seen |

The brick polls Telegram for new messages, so you don't need a public IP, port forwarding or a webhook.

### 8.4 Register and approve users

Each homeowner opens the bot and taps **Start**. New users begin with alerts turned off, so a stranger who finds the bot gets nothing. Turn alerts on for each person on the dashboard's **Telegram users** page at `https://<unoq-ip>:8443/users`.

<p align="center">
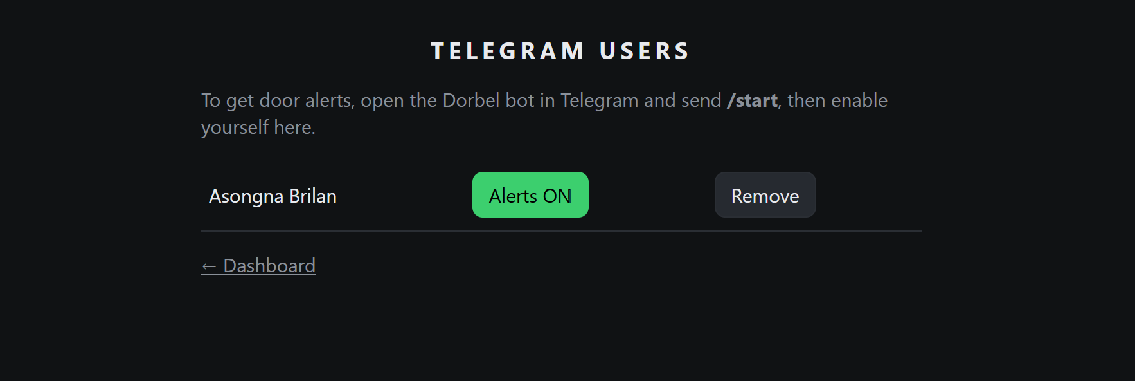
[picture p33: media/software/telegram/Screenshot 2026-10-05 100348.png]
Telegram users page with alerts turned on
  
</p>

> **✅ Check:** run the app. The **Python** tab shows `Telegram bot initialized successfully`. Press the doorbell and the approved phone gets a photo alert within a few seconds.

<p align="center">
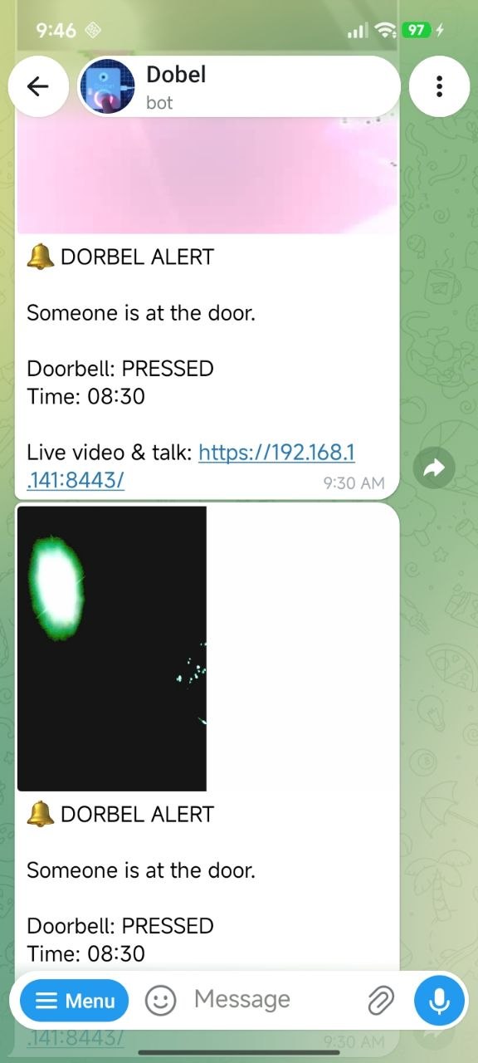
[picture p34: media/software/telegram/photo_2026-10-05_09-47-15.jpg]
Telegram ring alert
  
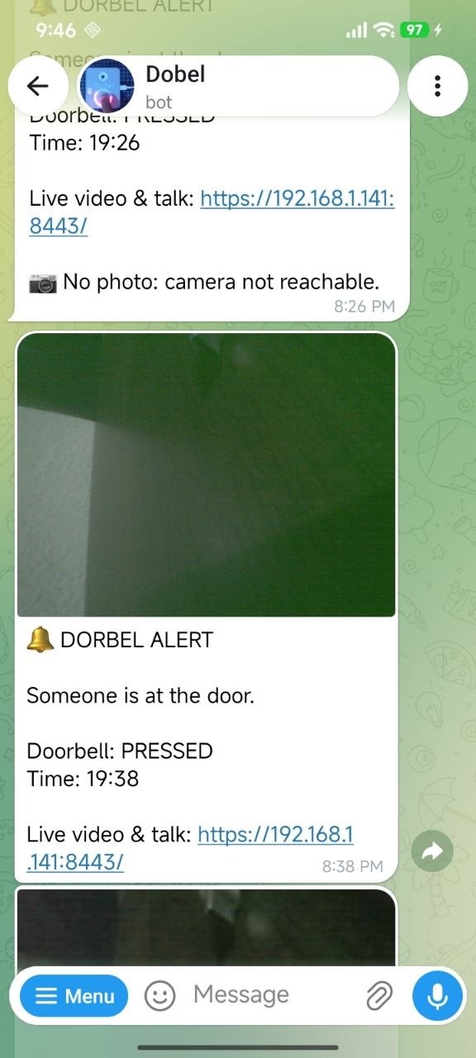
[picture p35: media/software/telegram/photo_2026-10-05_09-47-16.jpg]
Telegram alerts with photos
  
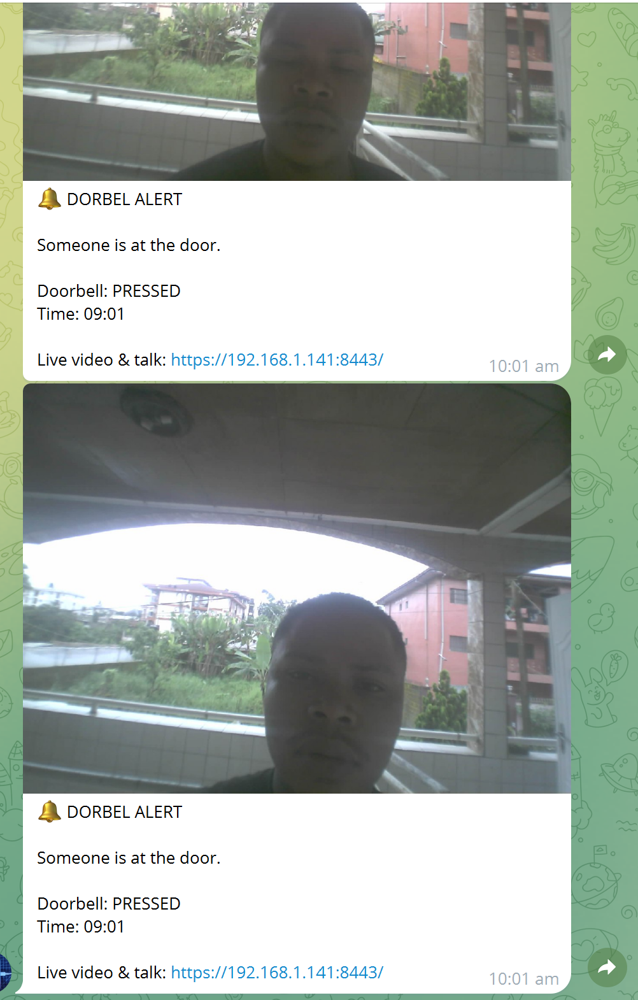
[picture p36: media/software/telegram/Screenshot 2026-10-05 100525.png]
Alerts showing the visitor
  
</p>
<p align="center">
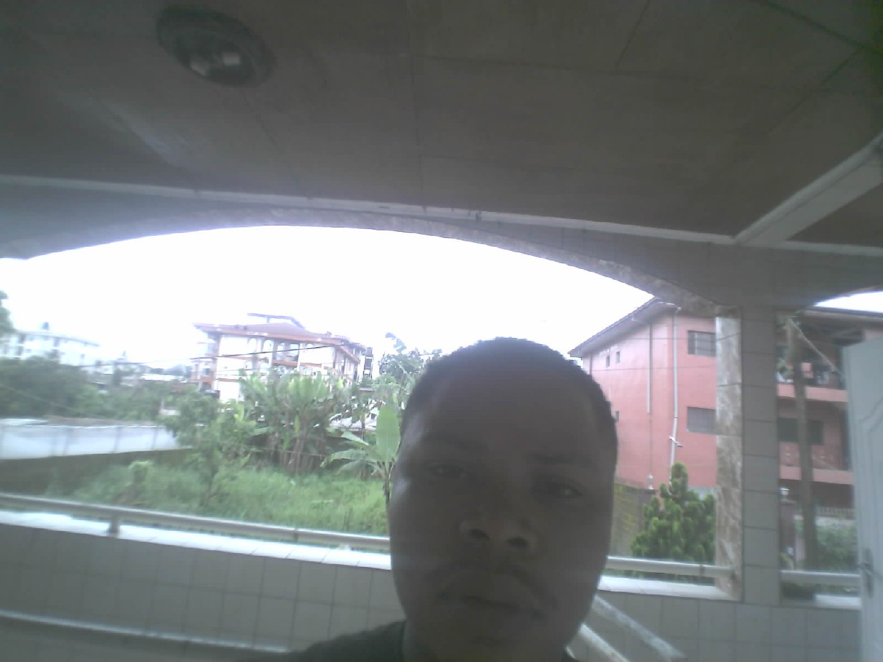
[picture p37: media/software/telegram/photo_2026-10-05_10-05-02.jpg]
Full resolution photo sent with an alert
  
</p>
<p align="center"><sub>The 1600×1200 photo that arrives with a ring alert</sub></p>

<br>

## 9. Assemble, mount and test

### 9.1 Fit the electronics

The RGB LED sits behind the light ring in the base. The XIAO and the button mount on the cover, with the camera behind the front hole.

<p align="center">
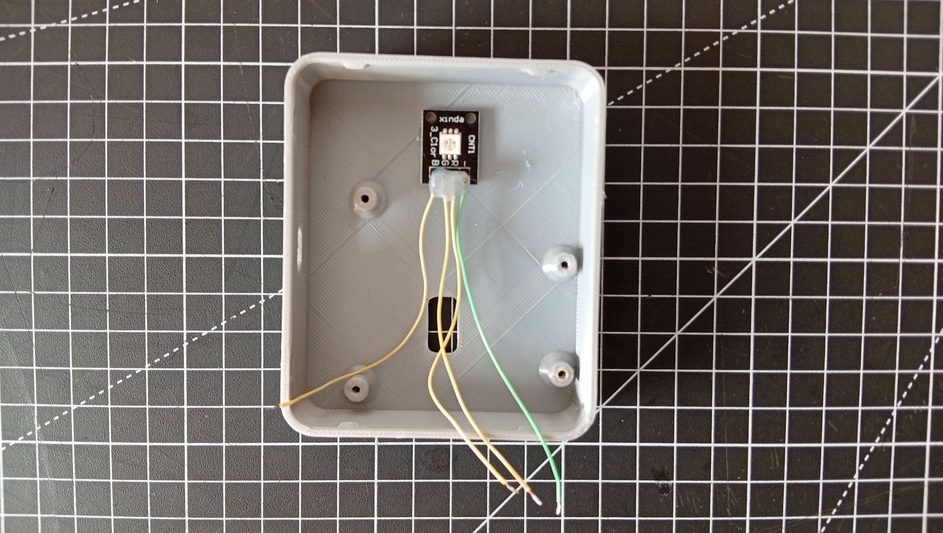
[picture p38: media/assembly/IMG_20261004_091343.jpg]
RGB LED fitted in the base
  
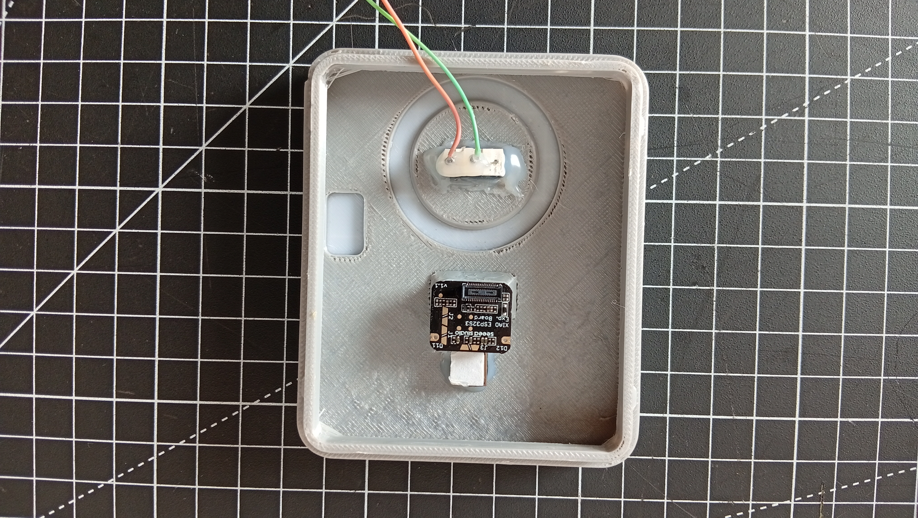
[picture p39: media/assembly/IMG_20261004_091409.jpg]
XIAO and button fitted in the cover
  
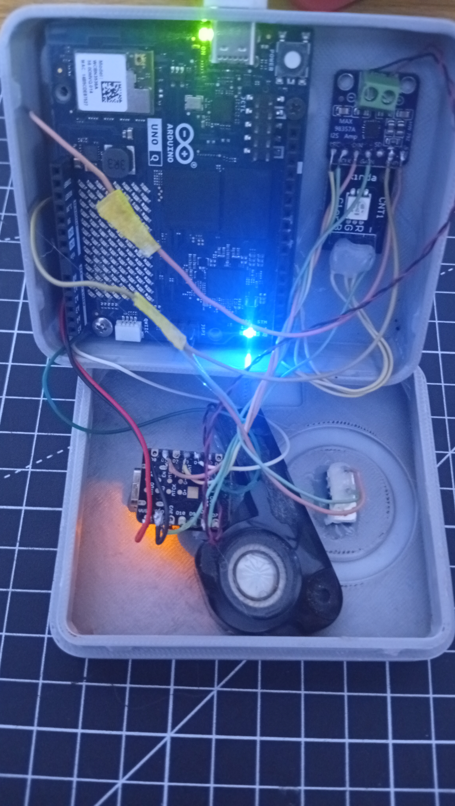
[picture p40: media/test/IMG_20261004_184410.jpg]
Everything wired inside the enclosure
  
</p>

### 9.2 Close it up

Close the enclosure and check that the ring lights up through the cover.

<p align="center">
  Closed doorbell
  Light ring during the day
  Light ring at night
</p>

### 9.3 Mount it

Screw the wall plate next to the door, then slide the doorbell onto its hook.

<p align="center">
  Wall mount plate
  Doorbell back and the wall mount
  Sliding the doorbell onto the mount
  Doorbell next to the mount
</p>

### 9.4 Test everything

- [ ] The **Python** tab shows `Camera reachable at <ip>` and `Telegram bot initialized successfully`
- [ ] The LED is green and the dashboard shows SYSTEM `ONLINE` with live video
- [ ] The AI panel shows `RUNNING`, and walking up brings a person badge, a boxed photo and a Telegram `👤` alert
- [ ] Pressing the button plays the chime, turns the LED red, shows DOORBELL `PRESSED` and sends a Telegram `🔔` photo
- [ ] **Test door speaker** plays two beeps and **Hold to talk** carries your voice to the door
- [ ] `/photo` and `/status` both reply in Telegram

<p align="center">
  Finished Dorbel
  Dorbel with the ring lit
  Dorbel from the side
  Dorbel from the back
</p>

<br>

## Troubleshooting

| Problem | Fix |
|---|---|
| Video never loads, alerts have no photo, log says `NOT reachable` | The XIAO and UNO Q are on different networks. Put both on the same 2.4 GHz Wi-Fi. |
| LED is blue or SYSTEM shows `XIAO OFFLINE` | Check the I²C wiring: A4 and A5, shared GND, 4.7 kΩ pull-ups. The XIAO must run `APP_MODE_DORBEL`. |
| App Lab says `Variable "TELEGRAM_BOT_TOKEN" is required` | Keep the placeholder under `arduino:telegram_bot` in `app.yaml`. |
| The Python tab says `Telegram disabled` | The token is missing from `python/dorbel_config.py`. |
| No alerts and the log says `No enabled Telegram users` | Turn alerts on for the user on the `/users` page. |
| AI shows `WAITING FOR CAMERA` | Same cause as video not loading. |
| AI misses people or reacts to shadows | Lower or raise `PERSON_CONFIDENCE` and check how the camera is aimed. |
| Talk says the microphone needs the secure dashboard | Use `https://...:8443`, not `http://...:8000`. |

You'll find more problems and their causes in [docs/REFERENCE.md](docs/REFERENCE.md#troubleshooting).

<br>

## How AI was used in this project

### 1. AI running on the doorbell

Person detection is a neural network running on the UNO Q itself, with no cloud service involved.

| | |
|---|---|
| **Brick** | App Lab Video Object Detection (`arduino:video_object_detection`) |
| **Model** | YoloX nano, an object detector trained on the COCO dataset and packaged by Edge Impulse (`yolo-x-nano.eim`) |
| **Where it runs** | The brick's Edge Impulse model runner on the UNO Q's Linux side |
| **Input** | 320×240 frames from the XIAO camera, passed in through `XiaoCamera` |
| **What Dorbel uses** | `person` boxes and confidence, which drive the dashboard badge, the boxed snapshot, the VISITOR state and the Telegram alert |

I picked this model because it is App Lab's default general purpose detector for the UNO Q, it works out of the box and it returns bounding boxes that can be counted and drawn. The alternative, the *Person classification* model for the Video Image Classification brick, only answers "person or no person" for the whole frame. The brick also accepts custom Edge Impulse models, so a model trained for something like "parcel at the door" could replace YoloX later without code changes.

### 2. AI helping with the final integration

I designed and built Dorbel myself: the hardware, the enclosure, the XIAO firmware, the App Lab app and the testing of each subsystem on the bench. Once everything worked on its own, I used an AI coding assistant (Claude Code) to help put the final pieces together:

- adding the Video Object Detection brick and making it work with the XIAO's Wi-Fi camera instead of a USB camera, through the shared `CameraHub` and the `XiaoCamera` adapter,
- moving the Telegram alerts onto the official Telegram Bot brick and adding the `/photo`, `/status` and `/help` commands,
- adding the AI panel to the dashboard,
- checking the changes on the board by reading the app logs, and fixing the issues that came up,
- drafting this guide from my notes and photos.

Every change was tested on the real doorbell before it went in.

<br>

## Credits

The dashboard and Telegram flow follow [Q04 Trillo](https://gitlab.com/supermoderno/q04_trillo). The speaker wiring follows [Xiaozhi-for-XiaoESP32S3](https://github.com/TechTalkies/Xiaozhi-for-XiaoESP32S3).

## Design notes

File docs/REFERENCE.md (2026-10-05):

# Dorbel – technical reference

The step-by-step build guide is in the [main README](../README.md). This file is the reference
material behind it: architecture, pin map, I²C protocol, power, code layout, per-subsystem
bring-up tests, the demo run sheet and the full troubleshooting table.

Repository paths below (`xiao/…`, `python/…`, `sketch/…`) are relative to the repository root.

## Contents

- [Architecture](#architecture-v1-locked) · [Pin map](#pin-map) · [I²C protocol](#ic-protocol) · [Power](#power)
- [Code base](#code-base) · [Build order and test status](#build-order-and-test-status)
- [Dorbel V1](#dorbel-v1-camera--push-to-talk--dashboard--telegram)
  - [Bill of materials](#bill-of-materials)
  - [Full setup guide](#full-setup-guide) (wiring → Wi-Fi → XIAO → UNO Q → Telegram bot → browser)
  - [Live demo](#live-demo) (pre-flight checklist, run sheet, fallbacks)
  - [Troubleshooting](#troubleshooting)
- [Finishing V1](#finishing-v1)

---

## Architecture (V1, locked)

```
                    ┌──────────────────────┐
                    │        DORBEL        │
                    └──────────┬───────────┘
                ┌──────────────┴──────────────┐
                ▼                             ▼
       XIAO ESP32S3 Sense              Arduino UNO Q 4GB
       Multimedia endpoint                System brain
       ┌────────┼─────────┐               ┌────┴─────┐
       ▼        ▼         ▼               ▼          ▼
    CAMERA     MIC      I2S OUT         BUTTON      RGB
       └────────┴─────────┘
                │ Wi-Fi
                ▼
         UNO Q / Browser
        ┌───────┴─────────┐
        ▼                 ▼
     Dashboard         Telegram

XIAO ←──────── I²C control/status ────────→ UNO Q
```

**Main rule:** I²C carries **control and status only**. Wi-Fi carries **video and two-way
audio**. Camera frames and audio never go over I²C.

---

## Pin map

### XIAO ESP32S3 Sense

| Function | XIAO pin | GPIO | Connects to |
|---|---|---|---|
| I²C SDA (slave, `0x08`) | D4 | GPIO5  | UNO Q A4 (SDA) |
| I²C SCL | D5 | GPIO6  | UNO Q A5 (SCL) |
| PDM mic clock (onboard) | — | GPIO42 | onboard |
| PDM mic data (onboard)  | — | GPIO41 | onboard |
| I2S BCLK | D8 | GPIO7  | MAX98357A BCLK |
| I2S LRC / WS | D3 | GPIO4  | MAX98357A LRC |
| I2S DOUT | D1 | GPIO2  | MAX98357A DIN |
| 5V | 5V | — | MAX98357A VIN |
| GND | GND | — | MAX98357A GND, UNO Q GND |

D11/D12 are avoided for audio because on the Sense board they are GPIO42/GPIO41, which the
onboard microphone uses. Camera pins are listed in `xiao/include/camera_pins.h`.

### MAX98357A → speaker

```
MAX98357A SPK+ ──┐
                 ├── 8 Ω / 2 W speaker
MAX98357A SPK- ──┘
```

> ⚠️ The MAX98357A output is bridge-tied. Connect the speaker between **SPK+ and SPK-**. Never
> connect SPK- to GND.

### Arduino UNO Q

| Function | UNO Q pin | Notes |
|---|---|---|
| Push button | D2 | to GND, `INPUT_PULLUP` |
| RGB red | D3 | via 220 Ω |
| RGB green | D5 | via 220 Ω |
| RGB blue | D6 | via 220 Ω |
| I²C SDA | **A4** (D18, PC1) | to XIAO D4. `Wire2` in the sketch, **not** the D20/D21 header (`Wire`) |
| I²C SCL | **A5** (D19, PC0) | to XIAO D5 |

The RGB LED is assumed to be common-cathode, with the common pin to GND. If yours is
common-anode, set `LED_COMMON_ANODE 1` in the UNO Q sketches.

V1 has no door sensor. The reed switch on D7 from the original plan has been dropped.

---

## I²C protocol

- **UNO Q = master** (`Wire2.begin()`, A4/A5). The UNO Q docs demonstrate the board as master,
  so it is the lower-risk choice.
- **XIAO = slave at `0x08`**, using `Wire.onReceive()` / `Wire.onRequest()`.

| Direction | Message | Value  |
|---|---|---|
| UNO Q → XIAO | `CMD_PING` | `0x01` |
| UNO Q → XIAO | `CMD_RING` | `0x02` |
| UNO Q → XIAO | `CMD_TALK_ON`  | `0x03` |
| UNO Q → XIAO | `CMD_TALK_OFF` | `0x04` |
| UNO Q → XIAO | `CMD_GET_IP` | `0x05`. The next read returns 4 bytes, the XIAO's IPv4 `a.b.c.d` (`0.0.0.0` = no Wi-Fi) |
| XIAO → UNO Q | status byte (bit flags) | `STATUS_ALIVE` 0x01 (Wi-Fi connected in `APP_MODE_DORBEL`), `STATUS_CAMERA` 0x02, `STATUS_AUDIO` 0x04, `STATUS_TALK` 0x08 (homeowner talking) |

The UNO Q learns the XIAO's IP over I²C, so the dashboard finds the camera without any setup.

---

## Power

```
            8–12 V BATTERY
                  │
          ┌───────┴────────┐
          ▼                ▼
      UNO Q VIN         5 V BUCK
      (7–24 V)             │
                    ┌──────┴──────┐
                    ▼             ▼
                  XIAO        MAX98357A
                    └──── GND ────┘   (all grounds common)
```

Do not feed the battery directly into the XIAO or the MAX98357A.

**Bench setup during development:** power the UNO Q and the XIAO from USB-C each, and power the
MAX98357A from the XIAO's 5V pin.

---

## Code base

The repository holds two firmware targets, laid out so each tool opens its own part:

- **UNO Q:** the repo root **is** the Arduino App Lab app (`app.yaml` + `sketch/` + `python/`).
  Clone it into `~/ArduinoApps/dorbel` on the UNO Q and it shows up in App Lab as **Dorbel**.
- **XIAO ESP32S3 Sense:** a PlatformIO project in `xiao/`. Open **that folder** (not the repo
  root) in VS Code / PlatformIO.

```
app.yaml                  App Lab app metadata ("Dorbel"), exposes dashboard ports 8000 + 8443
sketch/                   UNO Q STM32 sketch: button, RGB, I²C master, Bridge RPC
  sketch.ino
  sketch.yaml             arduino:zephyr + Arduino_RouterBridge
python/                   Linux side (App Lab Python container, no extra pip installs)
  main.py                 polls the Bridge, keeps state + event log, wires the bricks together
  camera_hub.py           one shared XIAO stream for dashboard viewers + the AI brick (XiaoCamera)
  vision.py               person detection with the Video Object Detection brick (YoloX nano)
  dashboard.py            HTTP :8000 + HTTPS :8443 (page, JSON API, video/audio/photo relay)
  dashboard.html          video, status, AI person detection, push-to-talk, events
  users.html              enable/disable Telegram users
  notifier.py             Telegram Bot brick: /start /photo /status /help + door and person alerts
  dorbel_config_example.py  settings template → copy to dorbel_config.py (gitignored)
  certs/                  self-signed HTTPS certificate, made on first start (gitignored)
xiao/                     XIAO PlatformIO project — open this folder in PlatformIO
  platformio.ini          board, PSRAM (qio_opi), huge_app partition, USB-CDC serial
  include/
    camera_pins.h         OV2640 pin map for the Sense board
    dorbel_protocol.h     I²C address, CMD_* and STATUS_* values (mirrored in UNO Q sketches)
    mic_capture.h         mic WAV capture API
    mic_level.h           live mic level meter API
    speaker_test.h        speaker API: initSpeaker(), playTone(), playChime()
    i2c_slave_test.h      I²C slave test API
    i2c_link.h            shared I²C slave: command queue, status byte, IP reply
    intercom.h            WebSocket push-to-talk intercom API
    secrets.example.h     Wi-Fi credentials template → copy to secrets.h (gitignored)
  src/
    main.cpp              APP_MODE selector, camera setup, Wi-Fi, APP_MODE_DORBEL integration
    app_httpd.cpp         HTTP servers: test-mode "/" + "/stream"; Dorbel mode :80 (+ /capture) + :81
    intercom.cpp          ws://<xiao>/audio: mic → browser, browser → speaker, chime
    i2c_link.cpp          I²C slave at 0x08 (used by the test mode and Dorbel mode)
    speaker_test.cpp      MAX98357A over I2S port 1: tones + "ding-dong" chime
    mic_level.cpp         live mic RMS meter over serial (no SD card needed)
    mic_capture.cpp       10 s mic clip: /mic_test.wav if an SD card is present, else RMS over serial
    i2c_slave_test.cpp    I²C slave at 0x08: logs commands, answers status, plays chime on RING
unoq_tests/               earlier UNO Q step apps (each is app.yaml + sketch/ + python/)
  i2c_master_test/        step 10: PING + RING over I²C, prints XIAO status
  io_test/                step 11: button + RGB LED
  doorbell_ring/          step 12: button → I²C RING → XIAO chime
stl/                      enclosure models (base, cover, body)
```

### Running a UNO Q step test app

App Lab only lists apps that sit directly in `~/ArduinoApps/`. Because the repo root is the main
app, the step apps in `unoq_tests/` are not listed. To run one, copy it next to the main app:

```bash
cp -r ~/ArduinoApps/dorbel/unoq_tests/io_test ~/ArduinoApps/dorbel-io-test
```

It then appears in App Lab (e.g. "Dorbel IO Test"). Delete the copy when you're done. Edit the
original in `unoq_tests/` if you want the change kept in git.

### Selecting a subsystem test

Each subsystem is tested on its own before integration. To pick one, edit this line in
`xiao/src/main.cpp`:

```cpp
#define APP_MODE APP_MODE_DORBEL   // V1 (default), or _I2C_SLAVE / _SPEAKER_TEST / _MIC_LEVEL / _MIC_CAPTURE / _CAMERA_STREAM
```

### Arduino core version

The project is pinned to **arduino-esp32 core 2.x** (2.0.17, the default for PlatformIO's
`espressif32` platform). On this core:

- I2S uses the legacy `driver/i2s.h` and `I2S.h`. The core 3.x `ESP_I2S.h` / `I2SClass` API
  **does not exist** here.
- LEDC uses `ledcSetup()` + `ledcAttachPin()`.

The speaker test is a direct port of the reference `ESP_I2S` sketch: same pins, 16 kHz,
16-bit mono, standard I2S, same tones. If you later move to core 3.x, port the I2S and LEDC
calls together.

The microphone uses I2S port 0 and the speaker uses **I2S port 1**, so both can run at the same
time after integration.

### Build and flash

```bash
cd xiao                      # the PlatformIO project lives here
cp include/secrets.example.h include/secrets.h   # first time only; fill in Wi-Fi
pio run                      # build
pio run -t upload            # flash (close any open serial monitor first)
pio device monitor           # 115200 baud
```

PlatformIO's CLI is at `~/.platformio/penv/Scripts/pio.exe` if `pio` is not on your PATH.

> Serial runs over native USB. `setup()` waits up to 3 s for a USB host, then starts anyway,
> so the firmware also runs on battery.

---

## Build order and test status

| Step | Subsystem | Board | Code | Status |
|---|---|---|---|---|
| 1 | MAX98357A speaker | XIAO  | `APP_MODE_SPEAKER_TEST` | Builds, needs a test on the board |
| 2 | Onboard PDM mic, live RMS (no SD) | XIAO  | `APP_MODE_MIC_LEVEL` | Running on the board; voice response to confirm |
| 2b | PDM mic → WAV clip (SD optional) | XIAO  | `APP_MODE_MIC_CAPTURE` | Builds; SD-free fallback untested |
| 3 | Camera MJPEG stream → browser | XIAO  | `APP_MODE_CAMERA_STREAM` | Builds, re-test on the board |
| 4/10 | I²C link: UNO Q master ↔ XIAO `0x08` | both  | `APP_MODE_I2C_SLAVE` + `unoq_tests/i2c_master_test`  | XIAO flashed and running; UNO Q compiles, needs a test on the board |
| 11 | Button + RGB LED | UNO Q | `unoq_tests/io_test` | Compiles, needs a test on the board |
| 12 | Button → I²C RING → XIAO chime | both  | `unoq_tests/doorbell_ring` + `APP_MODE_I2C_SLAVE` | Compiles, needs a test on the board |
| 13–14| STM32 ↔ Linux Bridge RPC + Python poller | UNO Q | the main **Dorbel** app (repo root) | Working |
| 15 | Push-to-talk intercom over Wi-Fi | XIAO  | `APP_MODE_DORBEL` (`intercom.cpp`) | Builds, needs a test on the board |
| 16–18| Dashboard + Telegram alerts | UNO Q | `python/` (main app) | Smoke-tested on a PC with a stub Bridge; needs a test on the board |
| 19 | V1 end-to-end demo | both  | see "Dorbel V1" below | Needs a test on the board |

### Subsystem 1: MAX98357A speaker test

1. Wire BCLK→D8, LRC→D3, DIN→D1, VIN→5V and GND→GND. Connect the speaker across SPK+/SPK-.
2. Set `APP_MODE_SPEAKER_TEST`, then flash.
3. Open the serial monitor. You should see `MAX98357A OK`, followed by `Playing doorbell test...`
   every ~3.9 s.
4. Pass condition: you hear a clean two-tone chime (880 Hz for 300 ms, then 659 Hz for 500 ms).

| Symptom | Likely cause |
|---|---|
| `I2S init FAILED` | I2S port or pin conflict. Check the pin defines in `speaker_test.cpp`. |
| Logs are fine but no sound  | VIN/GND not connected, BCLK and LRC swapped, or SD pin pulled low (shutdown mode). |
| Loud buzz or distortion | Speaker wired SPK-→GND, or amplitude too high. Lower `AMPLITUDE`. |
| Too quiet | Raise `AMPLITUDE` (max 32767), or run VIN at 5 V instead of 3.3 V.  |
| No serial output | Firmware waits for USB CDC. Reopen the monitor or press reset. |

### Subsystem 2: onboard microphone (no SD card needed)

The mic is the Sense board's PDM mic: clock on GPIO42, data on GPIO41, read on I2S port 0 at
16 kHz, 16-bit mono. The reference sketch uses the core 3.x `ESP_I2S` API, so it was ported to
the core 2.x `driver/i2s.h` API. In PDM mode the clock goes on the WS pin.

1. Set `APP_MODE_MIC_LEVEL`, then flash. No microSD card is required.
2. Open the serial monitor. You should see `MIC OK`, followed by a stream of `Mic RMS: <value>`
   lines (about 15 per second).
3. Pass condition: the value stays low when the room is quiet and jumps when you speak or clap
   near the board. The DC offset is subtracted, so RMS reflects sound only.

Measured on the bench: quiet room ≈ 5–25.

`APP_MODE_MIC_CAPTURE` no longer stops when no card is inserted. It still records 10 s into
PSRAM. If a card is mounted, it saves `/mic_test.wav`. Otherwise it prints one RMS value per
second.

| Symptom | Likely cause |
|---|---|
| `MIC INIT FAILED` | I2S port 0 already in use, or wrong pins. |
| RMS stuck at 0 | Sense expansion board not seated (the mic is on it). |
| RMS doesn't change when you speak | Clock and data pins swapped. Check GPIO42/41. |

### Subsystem 3: camera live stream (XIAO → Wi-Fi → browser)

1. Copy `xiao/include/secrets.example.h` to `xiao/include/secrets.h` and fill in the network details. The
   XIAO only supports **2.4 GHz** Wi-Fi.
2. Set `APP_MODE_CAMERA_STREAM` in `xiao/src/main.cpp`, then flash.
3. Open the serial monitor. It prints a Wi-Fi scan (and warns if your SSID isn't visible), then
   `Connected! Open http://<ip>/`.
4. From a device on the same network, open `http://<ip>/` for the viewer page, or
   `http://<ip>/stream` for the raw MJPEG stream.
5. Pass condition: live, upright video at QVGA (320×240) that keeps updating.

| Symptom | Likely cause |
|---|---|
| `Camera init failed with error 0x…`  | Sense board not seated on the XIAO, or PSRAM not enabled (`qio_opi` in `xiao/platformio.ini`). |
| SSID "NOT in the scan results" | Network is 5 GHz-only, out of range, or the SSID doesn't match exactly. |
| Connects, but the page won't load | Browser is on a different network, or client isolation on a phone hotspot. |
| Image is upside down | Change `set_vflip` in `configureCamera()`. |
| Stream stutters | Weak signal. Check RSSI in the scan, or move closer. |

Only one browser tab can view `/stream` at a time. The HTTP server handles one stream client.
The UNO Q dashboard will later re-serve the stream to everyone else.

### Subsystem 4: XIAO ↔ UNO Q I²C link

**Wiring.** Keep the wires short.

```
XIAO D4 / GPIO5 (SDA) ──────┬─── UNO Q A4 (SDA, PC1)
XIAO D5 / GPIO6 (SCL) ────┬─┼─── UNO Q A5 (SCL, PC0)
XIAO GND ─────────────────┼─┼─── UNO Q GND
                         4.7k 4.7k  → 3.3 V   (one pair of pull-ups for the whole bus)
```

I²C needs pull-ups. Neither the XIAO's D4/D5 nor the UNO Q's A4/A5 are documented as having
them, so add **4.7 kΩ from SDA to 3.3 V and from SCL to 3.3 V**. Both boards use 3.3 V logic,
so no level shifter is needed.

**Which `Wire` object on the UNO Q?** The bus is set in the UNO Q Zephyr core's board file
(`arduino:zephyr` 1.0.0, `variants/arduino_uno_q_stm32u585xx`):

| Object  | Peripheral | Pins |
|---|---|---|
| `Wire`  | i2c2 | D20 (SDA) / D21 (SCL) header  |
| `Wire1` | i2c4 | Qwiic connector |
| `Wire2` | i2c3 | **A4 = PC1 (SDA), A5 = PC0 (SCL)** ← Dorbel |

Using `Wire` would drive D20/D21, and the XIAO on A4/A5 would never answer. If you rewire to
D20/D21, change `#define DORBEL_WIRE Wire2` to `Wire` in the master sketch.

**XIAO (slave).** Set `APP_MODE_I2C_SLAVE`, then flash. The serial output should show
`XIAO I2C slave ready at 0x08`, followed by a `[stats]` line every 5 s.

**UNO Q (master), step 10.** Copy `unoq_tests/i2c_master_test` into `~/ArduinoApps/` (see
"Running a UNO Q step test app"), then open it in Arduino App Lab and run it. All UNO Q
sketches use `Arduino_RouterBridge` (declared in each `sketch/sketch.yaml`) and print with
`Monitor`, because on the UNO Q MCU, `Serial` only reaches the D0/D1 UART pins. These sketches
are adapted from the reference ones in two ways: `Wire` → `Wire2` (A4/A5) and `Serial` →
`Monitor`.

The sketch sends `PING` once, then repeats: read status, wait 1 s, send `RING`, wait 3 s.

**Pass condition.** UNO Q (App Lab console):

```
UNO Q I2C master ready
Command 1 result = 0
XIAO status: 0x07
Command 2 result = 0
```

XIAO (serial monitor): `RING COMMAND RECEIVED`, and the speaker plays the chime. In
`APP_MODE_I2C_SLAVE` the XIAO starts the MAX98357A, plays the chime on every RING, and reports
`STATUS_AUDIO` only if the speaker started. Status `0x03` therefore means the link works but the
speaker failed to start.

| Symptom | Likely cause |
|---|---|
| `result = 2` (address NACK) | Missing GND or pull-ups, SDA/SCL swapped, XIAO not in `APP_MODE_I2C_SLAVE`, or `Wire` used instead of `Wire2`. |
| `result = 0` but `No XIAO response`  | Slave too slow to answer. Keep 100 kHz. |
| Intermittent errors | Long or loose wires, pull-ups missing or too weak. |
| No output in App Lab | Output went to `Serial` instead of `Monitor`, or the delay after `Monitor.begin()` was removed. |

To compile all UNO Q sketches from the command line:

```bash
arduino-cli compile --fqbn arduino:zephyr:unoq sketch
for s in i2c_master_test io_test doorbell_ring; do
  arduino-cli compile --fqbn arduino:zephyr:unoq unoq_tests/$s/sketch
done
```

### Subsystem 5: button + RGB (step 11)

There is no door sensor in V1.

```
UNO Q D2 ── button ── GND          (INPUT_PULLUP, pressed = LOW)
UNO Q D3 ──220Ω── R ┐
UNO Q D5 ──220Ω── G ├── RGB LED, common cathode → GND
UNO Q D6 ──220Ω── B ┘
```

Run `unoq_tests/io_test`.

**Pass condition:** the LED is **green** after boot. Holding the button turns it **red** and
prints `DOORBELL PRESSED`.

### Button → I²C → XIAO → speaker (step 12)

```
BUTTON → UNO Q → I²C RING (0x02) → XIAO → MAX98357A → SPEAKER
```

1. Flash the XIAO in `APP_MODE_I2C_SLAVE`. The speaker must be wired as in Subsystem 1.
2. Run `unoq_tests/doorbell_ring` on the UNO Q.

The button is debounced and triggers once per press. Presses within 1.5 s of a ring are ignored
while the chime plays. The UNO Q polls the XIAO status every second without blocking.

| LED | Meaning |
|---|---|
| Green | Idle, XIAO answering on I²C |
| Red | Ring just sent (1 s) |
| Blue  | XIAO not answering. Check wiring or XIAO mode. |

**Pass condition:** each press turns the LED red for 1 s, prints `DOORBELL PRESSED -> RING sent`,
and the speaker plays the chime. Unplugging the XIAO turns the LED blue.

### UNO Q STM32 ↔ Linux Bridge (steps 13–14)

the main **Dorbel** app (repo root) is step 12 plus a small RPC API that the STM32 exposes to Python on the
Linux side with `Bridge.provide_safe()`:

| RPC | Returns |
|---|---|
| `get_doorbell_state()` | `1` if the button was pressed since the last `clear_event()` |
| `get_xiao_status()` | last XIAO status byte, `-1` if the XIAO isn't answering |
| `clear_event()` | clears the doorbell flag, returns `1` |

`provide_safe` handlers run between `loop()` iterations on the MCU. So `loop()` never blocks for
long, otherwise `Bridge.call()` from Python stalls.

`python/main.py` polls every 0.5 s and prints the state. When it sees a press, it prints
`RING event received from MCU` and calls `clear_event()`, so each press is reported once.

**Pass condition.** The App Lab Python console shows `doorbell=0 xiao=0x07` while idle. Pressing
the button gives:

```
doorbell=1 xiao=0x07
RING event received from MCU
```

At the same time the chime plays and the LED flashes red. At this point both paths are proven:

```
Physical:  button → STM32 → I²C → XIAO → speaker
Software:  STM32 → Bridge RPC → Linux Python
```

The Linux side is where the Flask dashboard and Telegram notifications from Trillo will connect.

---

## Dorbel V1: camera + push-to-talk + dashboard + Telegram

```
VIDEO   XIAO :81/stream ──Wi-Fi──► UNO Q CameraHub ──► /stream ──https──► browsers (any number)
                                              └──► Video Object Detection brick ──► person events
LISTEN  XIAO ws /audio  ──Wi-Fi──► UNO Q /audio  ──wss────► browser   (16 kHz PCM)
TALK    browser mic ──wss──► UNO Q /audio ──Wi-Fi──► XIAO ──I2S──► MAX98357A
RING    button ─► UNO Q ─I²C RING─► XIAO chime
               └─► Bridge ─► python/main.py ─► XIAO /capture (1600×1200 photo)
                                            └─► Telegram Bot brick (photo + alert) + dashboard events
```

The UNO Q serves the dashboard and **relays** the XIAO's video, audio and photo, so a browser
only ever talks to the UNO Q. It learns the XIAO's IP over I²C (`CMD_GET_IP`) and must be able
to reach that IP, which means **the XIAO and the UNO Q must be on the same Wi-Fi network**.
The dashboard is served on `http://<unoq>:8000/` and `https://<unoq>:8443/`. Only the HTTPS
one can use the microphone (browsers block it on plain http). The intercom is **half duplex**:
while the homeowner holds TALK, the XIAO stops sending mic audio, so there is no feedback loop.

### XIAO endpoints (`APP_MODE_DORBEL`)

| URL | What |
|---|---|
| `http://<xiao>/` | bare camera page, handy for testing the XIAO on its own  |
| `http://<xiao>:81/stream` | MJPEG stream, on its own server so it never blocks audio. One client at a time: the UNO Q's CameraHub |
| `http://<xiao>/capture` | one 1600×1200 JPEG (`CAPTURE_FRAMESIZE`), used for the Telegram alert photo |
| `ws://<xiao>/audio` | intercom: binary = 16 kHz 16-bit LE mono PCM both ways; text `talk:1` / `talk:0` |

### Bill of materials

| Qty | Part | Notes |
|-----|---|---|
| 1 | Arduino UNO Q (4 GB) | system brain, runs the Dorbel App Lab app |
| 1 | Seeed XIAO ESP32S3 **Sense** | must be the Sense version (camera + mic expansion board seated) |
| 1 | MAX98357A I2S amplifier breakout | |
| 1 | 8 Ω / 2 W speaker | across SPK+ / SPK- |
| 1 | Momentary push button | the doorbell |
| 1 | RGB LED, common cathode, + 3 × 220 Ω | status light |
| 2 | 4.7 kΩ resistors | I²C pull-ups to 3.3 V |
| — | Jumper wires, breadboard | keep I²C wires short |
| 2 | USB-C data cables | one per board (bench power and flashing) |
| — | 2.4 GHz Wi-Fi with internet | XIAO is 2.4 GHz only. The UNO Q must join the **same** network. It needs internet for Telegram |
| — | A phone with Telegram | receives the alerts |
| — | A laptop or phone with a modern browser | the dashboard (TALK uses the `https://` dashboard) |

### Full setup guide

Do the steps in order. Each step has a check. Don't move on until it passes.

> **The one rule that breaks everything if missed:** the XIAO and the UNO Q must be on the
> **same 2.4 GHz Wi-Fi network** (same router, same `192.168.x.*` subnet). The XIAO can't join
> 5 GHz networks. If the UNO Q is on a 5 GHz SSID (e.g. `MyWifi-5GHZ`) and the XIAO on a laptop
> hotspot, the dashboard shows the status but the video never loads, TALK can't connect and the
> Telegram alert has no photo. The log then says `Camera at <ip> is NOT reachable`.

#### Step 1: Wire everything

Follow the [Pin map](#pin-map). In short:

```
XIAO D4 (SDA) ──┬── UNO Q A4          UNO Q D2 ── button ── GND
XIAO D5 (SCL) ──┼┬─ UNO Q A5          UNO Q D3 ─220Ω─ R ┐
XIAO GND ───────┼┼─ UNO Q GND         UNO Q D5 ─220Ω─ G ├─ RGB, common → GND
              4.7k 4.7k → 3.3 V       UNO Q D6 ─220Ω─ B ┘

XIAO D8 → MAX BCLK   XIAO D3 → MAX LRC   XIAO D1 → MAX DIN
XIAO 5V → MAX VIN    XIAO GND → MAX GND  MAX SPK+ / SPK- → speaker (never SPK- to GND)
```

**Check:** the grounds of both boards are connected, and there is one pair of pull-ups on SDA/SCL.

#### Step 2: Pick the Wi-Fi network

Choose one **2.4 GHz** network with internet that both boards will use, usually your home
router's 2.4 GHz SSID. A phone hotspot works too (on iPhone, turn on *Maximize
Compatibility*). A Windows laptop hotspot gives `192.168.137.x` addresses and only works if the
UNO Q joins it as well.

See which network the UNO Q is on, and list the networks it can see (`FREQ` 24xx = 2.4 GHz):

```bash
nmcli -t -f ACTIVE,SSID,FREQ dev wifi | grep '^yes'    # current network
nmcli -f SSID,FREQ,SIGNAL dev wifi list                # what's around
```

If the UNO Q is on a 5 GHz network, move it to the chosen 2.4 GHz one. Do this from the
board's own desktop or over USB (`adb shell`), not over SSH, because the SSH session drops
when the network changes:

```bash
sudo nmcli dev wifi connect "<SSID>" password "<password>"
hostname -I                                            # the new UNO Q IP, e.g. 192.168.x.z
```

**Check:** `nmcli` shows the chosen SSID with a `24xx` frequency.

#### Step 3: Flash the XIAO

On your PC, with [PlatformIO](https://platformio.org/) installed (VS Code extension or CLI):

```bash
cd xiao                                           # open THIS folder in PlatformIO, not the repo root
cp include/secrets.example.h include/secrets.h    # first time only
# edit include/secrets.h → WIFI_SSID / WIFI_PASSWORD of the network from Step 2
pio run -t upload                                 # close any serial monitor first
pio device monitor                                # 115200 baud
```

On Windows, use `~/.platformio/penv/Scripts/pio.exe` if `pio` isn't on PATH. Make sure
`xiao/src/main.cpp` has `#define APP_MODE APP_MODE_DORBEL` (the default).

**Check:** the serial log shows `Mode: Dorbel V1 (camera + intercom + I2C link)`, then
`XIAO I2C slave ready at 0x08`, then:

```
WiFi up: camera http://192.168.x.y/  stream http://192.168.x.y:81/stream  intercom ws://192.168.x.y/audio
```

Write the IP down. Its first three numbers must match the UNO Q's IP from Step 2 (e.g.
`192.168.1.50` and `192.168.1.141`). If they don't (e.g. `192.168.137.19`), the XIAO joined a
different network: fix `secrets.h` and flash again. To test the camera, open `http://<xiao-ip>/`
from a laptop on the same Wi-Fi. **Close that tab afterwards**: the XIAO streams to one client
only, and that slot belongs to the UNO Q's CameraHub.

#### Step 4: Put the Dorbel app on the UNO Q

The UNO Q runs Linux. Get a shell on it, either over the network
(`ssh arduino@<unoq-hostname>.local`) or over USB (`adb shell`). Then:

```bash
cd ~/ArduinoApps
git clone https://github.com/Asongnabrilan-nso/dorbel.git dorbel
cd dorbel/python
cp dorbel_config_example.py dorbel_config.py      # your local settings, gitignored
hostname -I                                       # note the LAN IP, e.g. 192.168.x.z
```

To update later, run `cd ~/ArduinoApps/dorbel && git pull`. Your `dorbel_config.py` and the
Telegram user DB are gitignored, so they survive updates.

Edit `python/dorbel_config.py` (`nano dorbel_config.py`). Set at least:

```python
DASHBOARD_URL = "https://192.168.x.z:8443/"  # the UNO Q LAN IP from `hostname -I`
```

App Lab runs the Python side in a container, so without this setting the Telegram alert could
link to an internal `172.x` address. Use the `https://…:8443/` address so the link opens a
dashboard where TALK works. Update it whenever the UNO Q's IP changes. Leave
`TELEGRAM_BOT_TOKEN` empty for now (Step 5).

**Check:** open **Arduino App Lab**. The app **Dorbel 🔔** is listed. Click **Run**. App Lab
compiles and flashes `sketch/` to the STM32 and starts `python/main.py`. The Python console
shows:

```
Telegram disabled: set TELEGRAM_BOT_TOKEN in python/dorbel_config.py
Dorbel dashboard: https://192.168.x.z:8443/
[event] System started
[event] MCU connected
[event] XIAO online
[event] Camera at 192.168.x.y
[event] Camera reachable at 192.168.x.y
```

If the last line says `Camera at 192.168.x.y is NOT reachable`, the boards are on different
networks. Go back to Step 2.

The RGB LED is **green**. If it's **blue**, the XIAO isn't answering on I²C. See
[Subsystem 4](#subsystem-4-xiao--uno-q-ic-link).

#### Step 5: Create and connect the Telegram bot

1. In Telegram, open **@BotFather** (the official one, with the blue check) and send `/newbot`.
2. Give it a display name (e.g. `Dorbel Front Door`), then a username that ends in `bot`
   (e.g. `dorbel_frontdoor_bot`). It must be unique across Telegram.
3. BotFather replies with a **token** like `123456789:AAH...`. Treat it like a password: it
   gives full control of the bot. Never commit it. It only goes in the gitignored
   `dorbel_config.py`.
4. Optional polish in BotFather:
   - `/setcommands` → pick your bot → send `start - Register for door alerts`
   - `/setdescription` → `Dorbel smart doorbell. Send /start to register.`
   - `/setuserpic` → upload a doorbell icon
5. Check the token from the UNO Q shell (this also confirms the board has internet):

   ```bash
   curl -s https://api.telegram.org/bot<TOKEN>/getMe
   # → {"ok":true,"result":{"id":...,"is_bot":true,"username":"dorbel_frontdoor_bot",...}}
   ```

6. Put the token in `python/dorbel_config.py`:

   ```python
   TELEGRAM_BOT_TOKEN = "123456789:AAH..."
   ```

   The **Telegram Bot** brick reads this token. `app.yaml` only holds a placeholder for the
   brick's required `TELEGRAM_BOT_TOKEN` variable, so the real token never lands in git.

7. **Stop and Run** the app again in App Lab. The `Telegram disabled` line is gone.
8. **Register each homeowner.** On their phone, open `t.me/<bot_username>` and tap **Start**
   (or send `/start`). The bot replies *"Welcome to Dorbel 🔔 … You are registered."* and the
   dashboard log shows `Telegram user registered: <name>`.
9. **Enable them.** Open `https://<unoq-ip>:8443/users` (the **Telegram users** link at the
   bottom of the dashboard) and click the toggle next to each name. New users start
   **disabled**, so strangers who find the bot get nothing.

How it works (`python/notifier.py`): the App Lab **Telegram Bot** brick long-polls Telegram,
so it needs no public IP, port forwarding or webhook. Users live in SQLite
(`python/dorbel_users.db`, max 10). On each ring, the CameraHub pauses the live stream and asks
the XIAO for a **1600×1200** photo (`/capture`; the XIAO switches to full resolution for that
one shot, see `CAPTURE_FRAMESIZE` in `xiao/src/app_httpd.cpp`), then the brick sends it to
enabled users with the alert text as the caption. If the photo fails, the latest live frame is
used; if there is none, the text goes out alone with `📷 No photo: camera not reachable`. The
brick retries each send. Ring alerts are limited to one every 10 s, AI person alerts to one
every `PERSON_ALERT_INTERVAL_S` (120 s).

**Check:** press the doorbell. Within a few seconds the enabled phone receives a photo with
`🔔 DORBEL ALERT … Someone is at the door.`, and the dashboard log shows
`Telegram alert sent to 1/1`.

#### Step 6: Open the dashboard and allow the microphone

Browsers only allow the microphone (`getUserMedia`) on `https://` or `localhost`, so the
dashboard is also served over HTTPS on port **8443** with a self-signed certificate (created
in `python/certs/` on first start). The video and audio are relayed through the UNO Q, so
the browser only has to reach the UNO Q, never the XIAO directly.

1. Open `https://<unoq-ip>:8443/` (the Telegram alert links here).
2. The browser warns about the certificate the first time. Choose **Advanced → Proceed**.
   Each browser needs this only once.

Plain `http://<unoq-ip>:8000/` still works for video and listening. Only TALK needs HTTPS.

**Using TALK:**

- **Hold** the button while you speak, or **tap** it once to start and tap again to stop. The
  space bar works the same way on a laptop.
- The first press asks for microphone permission. Allow it, then press again.
- The **green bar** under the button shows your microphone level. If it stays empty while you
  speak, the browser is getting no sound from your microphone, and the hint under the button
  says so.
- **🔔 Test door speaker** plays two beeps at the door without using your microphone. Use it
  to tell a speaker problem from a microphone problem.

**Check:** open `https://<unoq-ip>:8443/`. SYSTEM shows `● ONLINE` and video plays.
**🔔 Test door speaker** gives two beeps at the door. Holding **HOLD TO TALK** while you speak
moves the green bar, and your voice comes out of the door speaker (INTERCOM `● TALKING`).

You're ready to demo.

### Live demo

#### Pre-flight checklist (do this 30 min before)

- [ ] The XIAO and UNO Q are on the **same 2.4 GHz network** (the log shows `Camera reachable
      at <ip>`). The demo laptop must reach the UNO Q, and the phone needs internet for
      Telegram. The venue's Wi-Fi often has client
      isolation or captive portals. Bring your own travel router or phone hotspot (on iPhone:
      *Maximize Compatibility* = 2.4 GHz) and set its SSID in `secrets.h` and on the UNO Q
      ahead of time.
- [ ] Power both boards. Power-up order doesn't matter. The UNO Q picks up the XIAO within
      ~5 s.
- [ ] In App Lab, run **Dorbel**. LED is green, and the console shows `Camera reachable at <ip>`.
- [ ] `https://<unoq-ip>:8443/` open on the demo laptop (certificate accepted). SYSTEM
      `● ONLINE`, live video.
- [ ] Telegram open on the phone. The user is **enabled** on `/users`.
- [ ] Do one full dry run: ring, then listen, then talk. Wait **10 s** after the dry-run ring
      before the real one, because of the alert rate limit.
- [ ] Speaker volume is OK (adjust `MIC_GAIN` / amplitude beforehand, not live).
- [ ] Phone notifications are on and not muted. Mirror the phone screen if the room is big.

#### Run sheet (~5 minutes)

| # | Say | Do | Audience sees |
|---|-----|----|---|
| 1 | "Dorbel is a private, edge-processed smart doorbell: a UNO Q as the brain, a XIAO as eyes, ears and mouth." | Show the architecture diagram | I²C = control, Wi-Fi = media |
| 2 | "This is the homeowner's dashboard, served by the UNO Q itself, with no cloud." | Show the dashboard | SYSTEM ● ONLINE, live camera, event log |
| 3 | "A visitor arrives…" | **Press the doorbell** | Chime from the door speaker, LED red, DOORBELL ● PRESSED, VISITOR ● PRESENT |
| 4 | "…and the homeowner gets a photo, wherever they are." | Hold up / mirror the phone | Telegram photo + `🔔 DORBEL ALERT` |
| 5 | "I can hear who's there…" | Click **🔊 Listen to door**. Have a helper speak at the door | Door audio through the laptop |
| 6 | "…and answer them." | **Hold TALK** (or tap to latch it on) and speak | Voice from the door speaker, green level bar moving. INTERCOM ● TALKING, event `Intercom started` |
| 7 | "Only people I approve get alerts." | Open **Telegram users**, show the toggle | Access control without accounts or passwords |
| 8 | "Video and audio stay on the local network. Only the alert leaves the house." | Back to the dashboard | Event log of the whole demo |

Tips: the intercom is half-duplex, so pause after releasing TALK before the visitor answers.
Keep the laptop away from the door speaker to avoid echo when Listen is on.

#### If something goes wrong on stage

| Problem | Fast recovery |
|---|---|
| Video frozen | Reload the dashboard. If it stays frozen, check the event log for `Camera … NOT reachable`. |
| No Telegram message | Wait 10 s (rate limit) and ring again. Otherwise show the dashboard event log line `Telegram alert sent…` / `No enabled Telegram users`. |
| TALK blocked | Make sure the address starts with `https://` and port 8443. Otherwise carry on with Listen only. |
| SYSTEM `XIAO OFFLINE`, LED blue | Re-seat the I²C/GND wires, or reset the XIAO (it rejoins in ~10 s). |
| Nothing at all | Re-run the app in App Lab (~30 s). Keep a screen recording of a good run as a last resort. |

### Troubleshooting

| Symptom | Likely cause |
|---|---|
| Status loads but video keeps loading, no photo in alerts | XIAO and UNO Q on different networks. The log says `Camera at <ip> is NOT reachable`. See [Step 2](#step-2-pick-the-wi-fi-network). |
| Video says "not reachable" | Boards on different networks (above), or something else (e.g. `http://<xiao>/` in a browser tab) holds the XIAO's single stream slot. |
| TALK says "The microphone needs the secure dashboard" | You're on `http://…:8000`. Open the `https://…:8443/` link it shows. |
| Browser warns "Your connection is not private" | Expected: the certificate is self-signed. Choose **Advanced → Proceed** once. Delete `python/certs/` and restart to make a new one. |
| Dashboard unreachable from the phone  | Phone not on a network that reaches the UNO Q (e.g. on mobile data), client isolation, or App Lab didn't publish ports 8000/8443. Check `ports:` in `app.yaml`. |
| SYSTEM `MCU OFFLINE` | The STM32 sketch isn't running or hasn't registered its RPCs yet. Re-run the app. |
| SYSTEM `XIAO OFFLINE`, LED blue | I²C wiring/pull-ups/GND, or the XIAO isn't in `APP_MODE_DORBEL`. |
| SYSTEM `XIAO NO WI-FI` | Wrong SSID/password in `xiao/include/secrets.h`, or a 5 GHz-only network. |
| Telegram link points to a 172.x address | App Lab runs Python in a container. Set `DASHBOARD_URL` in `dorbel_config.py`. |
| `Telegram disabled` in the console | `TELEGRAM_BOT_TOKEN` empty, or `dorbel_config.py` not in `python/` next to `main.py`. |
| App Lab: `Variable "TELEGRAM_BOT_TOKEN" is required by brick "arduino:telegram_bot"` | The `variables:` placeholder under `arduino:telegram_bot` was removed from `app.yaml`. Put it back (any non-empty value). |
| `Failed to start brick 'TelegramBot'` / `InvalidToken` | Wrong token. Copy it again from BotFather (`/mybots` → API Token). |
| `Conflict: terminated by other getUpdates request` | Another copy of the app (e.g. on your PC) is polling the same bot, or a webhook is set. Stop the other copy, or run `curl https://api.telegram.org/bot<TOKEN>/deleteWebhook`. |
| `telegram.error.NetworkError: httpx.ReadError` now and then | A long-poll dropped. The brick reconnects on its own. If it persists, test with `curl https://api.telegram.org`. |
| AI shows `WAITING FOR CAMERA` | The CameraHub can't read the XIAO stream: same causes as "video keeps loading". |
| AI never detects anyone | Check the camera framing (people must be in view, upright and lit). Lower `PERSON_CONFIDENCE` (e.g. 0.4). Watch the model live at `http://<unoq-ip>:4912`. |
| Person alerts too frequent | Raise `PERSON_ALERT_INTERVAL_S` or `PERSON_CONFIDENCE`, or set `PERSON_ALERTS = False`. |
| `/start` gets no reply | App not running, or token error (see above). |
| Event `No enabled Telegram users to alert` | Enable the user on the `/users` page. |
| Alert arrives without a photo | The UNO Q can't reach the XIAO (different network, see Step 2), or the XIAO still runs firmware from before `CAPTURE_FRAMESIZE`. |
| Photo is glitchy or has grey stripes  | Lower `CAPTURE_FRAMESIZE` in `xiao/src/app_httpd.cpp` to `FRAMESIZE_SXGA` or `FRAMESIZE_XGA` and reflash. |
| TALK shows `Intercom started` / `ended` but nothing is heard at the door | Press **🔔 Test door speaker**. No beeps → speaker side: MAX98357A wiring/power, SPK+/SPK-, `Speaker OK` in the XIAO serial log. Beeps but no voice → your microphone: watch the green bar; if it stays empty, unmute it or pick the right one in the browser's site settings. |
| `Intercom ended` about 1 s after starting | The XIAO got no audio for 1 s (`TALK_TIMEOUT_MS`), so the browser isn't sending microphone audio. See the row above. |
| Voice too quiet at the door | Raise `TALK_GAIN` in `python/dashboard.html` (default 2), or the MAX98357A gain pin. |
| Talk audio choppy | Weak Wi-Fi. The XIAO buffers 100 ms; check RSSI in the serial scan. |
| Door audio too quiet or loud | `MIC_GAIN` in `xiao/src/intercom.cpp` (default 8). |
| No camera IP on the dashboard | Old UNO Q sketch without `get_xiao_ip`, or set `XIAO_HOST` in `dorbel_config.py`. |

V1 has no door sensor, so DOOR shows `NO SENSOR` and the alert leaves out the door state.
VISITOR is inferred: PRESENT for 2 minutes after a ring, a talk or an AI person detection.

---

## Finishing V1

V1 is code-complete: the XIAO firmware builds, and the UNO Q Python app has been checked on a
PC with a stubbed Bridge (ring → event → `/api/state`, pages served). What's left is hardware
validation and packaging:

- [ ] Run steps 1–12 in [Build order](#build-order-and-test-status) on the real boards, and
      update the Status column as each one passes.
- [ ] Full [setup guide](#full-setup-guide) on the bench, including the Telegram alert with
      photo.
- [ ] Two clean [demo](#live-demo) dry runs back to back.
- [ ] Tune `MIC_GAIN` and the speaker `AMPLITUDE` for the enclosure.
- [ ] Print the enclosure (`stl/`: base, cover, body, wall mount) and test-fit the button, LED,
      speaker and camera opening.
- [ ] Move from bench USB power to the battery + 5 V buck described in [Power](#power).
- [ ] Record a short video of the demo for the project write-up.

Ideas for after V1: a door reed switch (DOOR state), a custom Edge Impulse model (e.g. "parcel"
or "known face"), and Telegram inline buttons ("Talk now" / "Ignore").

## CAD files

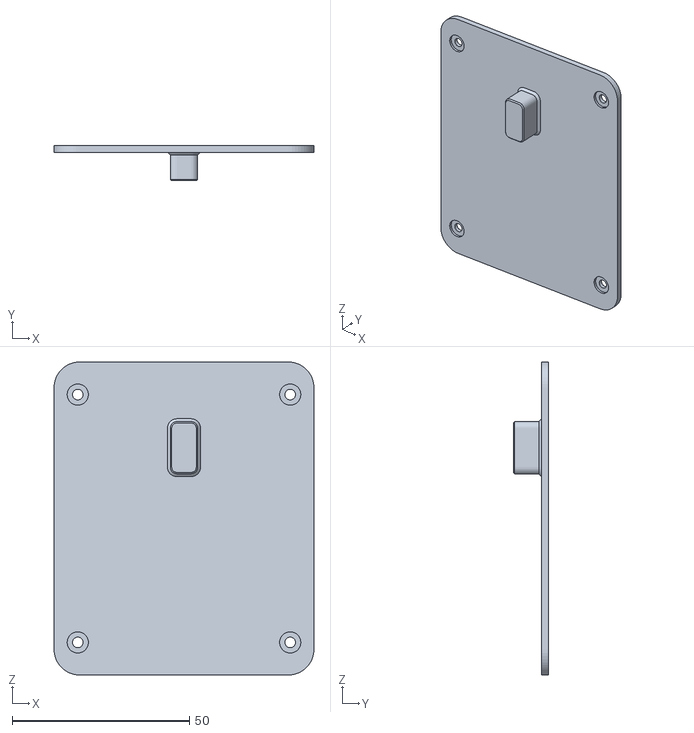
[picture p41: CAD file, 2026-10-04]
stl/wall mount.stl
73.4 x 10.0 x 88.4

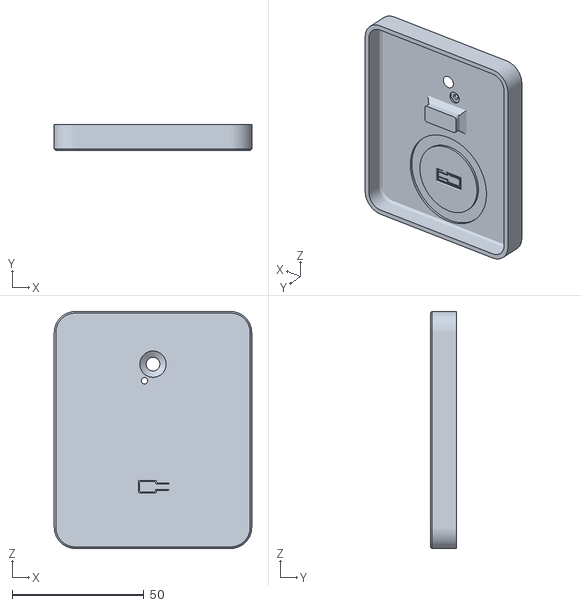
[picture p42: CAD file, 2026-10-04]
stl/Body2.stl
75.0 x 10.0 x 90.0

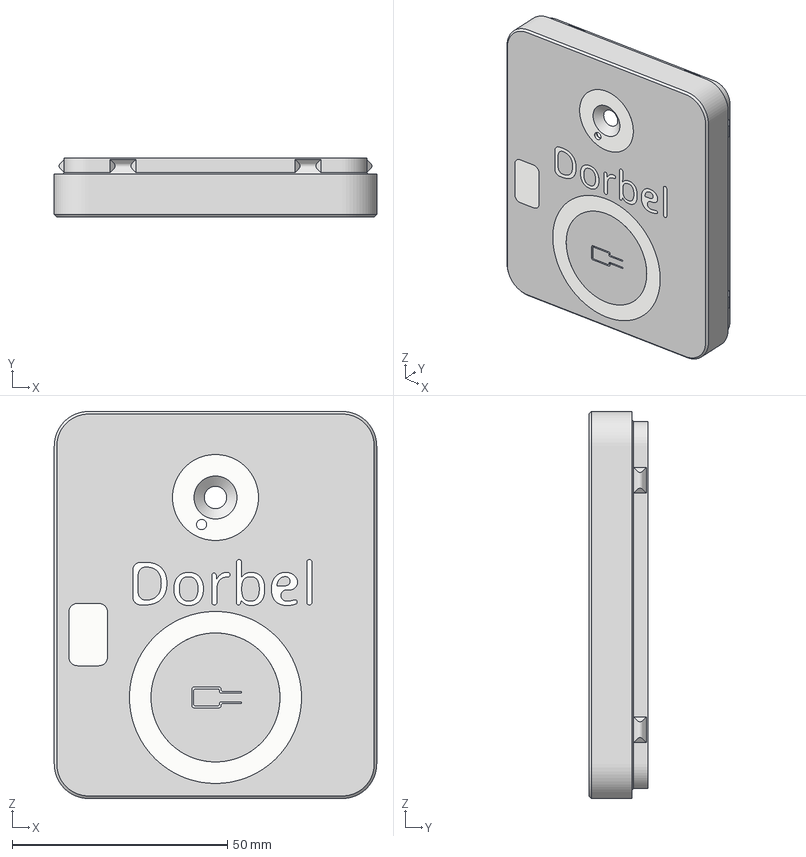
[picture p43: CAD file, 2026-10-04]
stl/Dorbel-Cover.3mf
75.0 x 13.8 x 90.0 mm

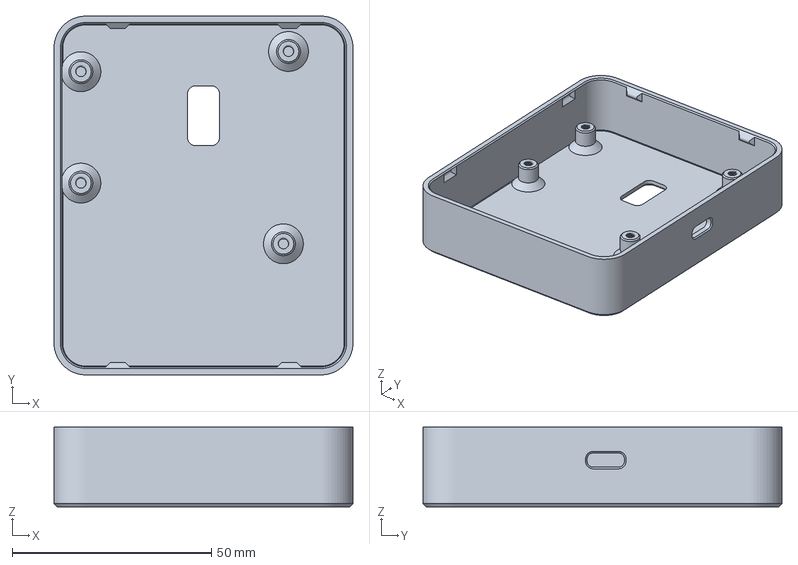
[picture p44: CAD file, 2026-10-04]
stl/Dorbel-Base.3mf
75.0 x 90.0 x 20.0 mm

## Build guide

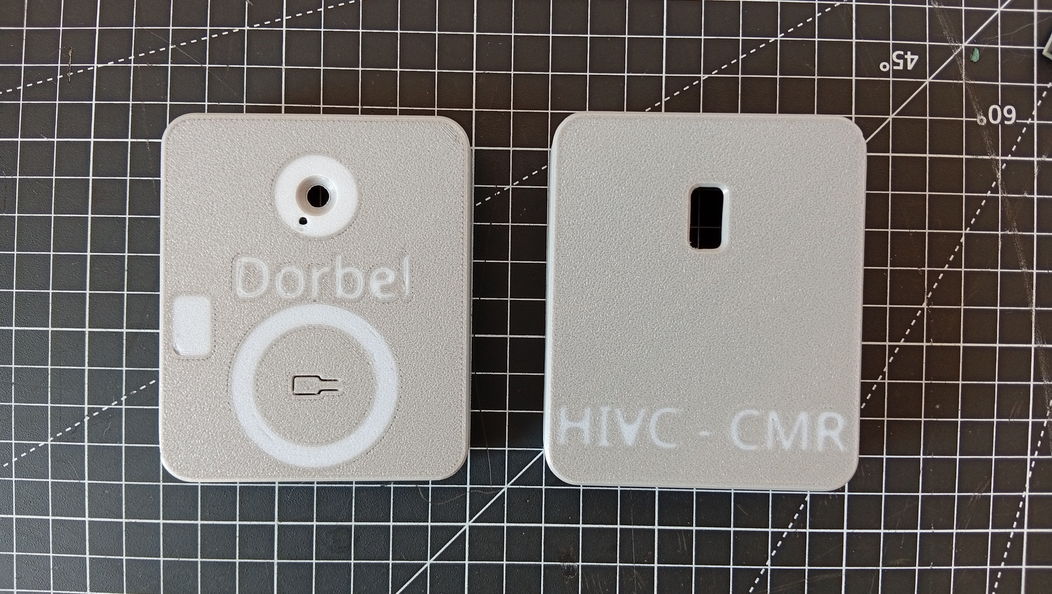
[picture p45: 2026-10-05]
media/assembly/IMG_20261004_082642.jpg

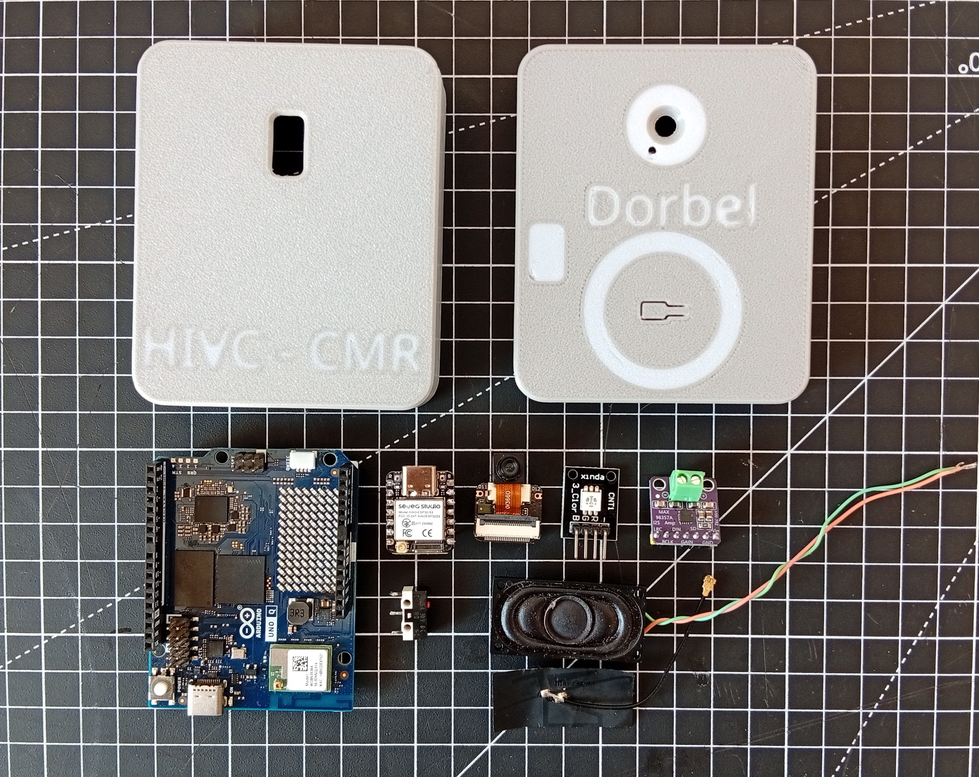
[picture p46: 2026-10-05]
media/assembly/IMG_20261004_082409.jpg

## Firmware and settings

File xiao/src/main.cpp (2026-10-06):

#include <Arduino.h>
#include <WiFi.h>
#include "esp_camera.h"
#include "camera_pins.h"
#include "secrets.h"
#include "mic_capture.h"
#include "speaker_test.h"
#include "mic_level.h"
#include "i2c_slave_test.h"
#include "i2c_link.h"
#include "intercom.h"
#include "dorbel_protocol.h"

// ---------------------------------------------------------------------
// Pick which subsystem test to run. Change this line and reflash to
// switch - each mode brings up one Dorbel subsystem on its own so it can
// be verified before final integration (camera and mic/SD share some
// GPIOs on the Sense board, see mic_capture.cpp).
// ---------------------------------------------------------------------
#define APP_MODE_CAMERA_STREAM 1
#define APP_MODE_MIC_CAPTURE   2
#define APP_MODE_SPEAKER_TEST  3
#define APP_MODE_MIC_LEVEL     4
#define APP_MODE_I2C_SLAVE     5
#define APP_MODE_DORBEL        6 // V1 integration: camera + intercom + I2C link
#define APP_MODE APP_MODE_DORBEL  

void startCameraServer();
void startDorbelServers(bool micOk, bool speakerOk);
void setupLedFlash(int pin);

static bool configureCamera() {
  camera_config_t config = {};
  config.ledc_channel = LEDC_CHANNEL_0;
  config.ledc_timer = LEDC_TIMER_0;
  config.pin_d0 = Y2_GPIO_NUM;
  config.pin_d1 = Y3_GPIO_NUM;
  config.pin_d2 = Y4_GPIO_NUM;
  config.pin_d3 = Y5_GPIO_NUM;
  config.pin_d4 = Y6_GPIO_NUM;
  config.pin_d5 = Y7_GPIO_NUM;
  config.pin_d6 = Y8_GPIO_NUM;
  config.pin_d7 = Y9_GPIO_NUM;
  config.pin_xclk = XCLK_GPIO_NUM;
  config.pin_pclk = PCLK_GPIO_NUM;
  config.pin_vsync = VSYNC_GPIO_NUM;
  config.pin_href = HREF_GPIO_NUM;
  config.pin_sccb_sda = SIOD_GPIO_NUM;
  config.pin_sccb_scl = SIOC_GPIO_NUM;
  config.pin_pwdn = PWDN_GPIO_NUM;
  config.pin_reset = RESET_GPIO_NUM;
  config.xclk_freq_hz = 20000000;
  config.frame_size = FRAMESIZE_UXGA;
  config.pixel_format = PIXFORMAT_JPEG;
  config.grab_mode = CAMERA_GRAB_WHEN_EMPTY;
  config.fb_location = CAMERA_FB_IN_PSRAM;
  config.jpeg_quality = 12;
  config.fb_count = 1;

  if (psramFound()) {
    config.jpeg_quality = 10; // lower = better quality, larger frames
    config.fb_count = 2;
    config.grab_mode = CAMERA_GRAB_LATEST;
  } else {
    // Fallback if PSRAM somehow isn't detected - keeps things working,
    // just at lower resolution using internal RAM.
    config.frame_size = FRAMESIZE_SVGA;
    config.fb_location = CAMERA_FB_IN_DRAM;
  }

  esp_err_t err = esp_camera_init(&config);
  if (err != ESP_OK) {
    Serial.printf("Camera init failed with error 0x%x\n", err);
    return false;
  }

  sensor_t *sensor = esp_camera_sensor_get();
  if (sensor->id.PID == OV3660_PID) {
    sensor->set_vflip(sensor, 1);     // flip it back
    sensor->set_brightness(sensor, 1); // up the brightness just a bit
    sensor->set_saturation(sensor, -2); // lower the saturation
  }
  // The sensor on the Sense board sits rotated relative to the enclosure -
  // flip vertically so the stream comes out right-side up.
  sensor->set_vflip(sensor, 1);
  // Drop down frame size for a higher initial frame rate; the web UI /
  // client can still request the full UXGA frame buffer size later.
  sensor->set_framesize(sensor, FRAMESIZE_QVGA);

#if defined(LED_GPIO_NUM)
  setupLedFlash(LED_GPIO_NUM);
#endif
  return true;
}

// Scans, then connects. timeoutMs = 0 waits forever; otherwise gives up after
// timeoutMs and leaves the ESP32 retrying in the background.
static bool connectWiFi(uint32_t timeoutMs) {
  WiFi.mode(WIFI_STA);
  WiFi.disconnect();
  delay(100);

  Serial.println("Scanning for WiFi networks...");
  int found = WiFi.scanNetworks();
  if (found <= 0) {
    Serial.println("  No networks found at all - check the board is powered "
                    "well and the hotspot is broadcasting on 2.4GHz.");
  } else {
    bool targetSeen = false;
    for (int i = 0; i < found; i++) {
      Serial.printf("  [%d] %s (RSSI %d, ch %d, %s)\n", i, WiFi.SSID(i).c_str(),
                    WiFi.RSSI(i), WiFi.channel(i),
                    WiFi.encryptionType(i) == WIFI_AUTH_OPEN ? "open" : "secured");
      if (WiFi.SSID(i) == WIFI_SSID) {
        targetSeen = true;
      }
    }
    if (!targetSeen) {
      Serial.printf("  Target SSID \"%s\" was NOT in the scan results - the "
                    "ESP32 can't see it. Likely a 5GHz-only hotspot, out of "
                    "range, or the SSID string doesn't match exactly.\n",
                    WIFI_SSID);
    }
  }

  WiFi.begin(WIFI_SSID, WIFI_PASSWORD);
  WiFi.setSleep(false); // avoid WiFi power-save stutter while streaming
  Serial.print("Connecting to WiFi");
  uint32_t start = millis();
  uint32_t attemptStart = millis();
  while (WiFi.status() != WL_CONNECTED) {
    if (timeoutMs && millis() - start > timeoutMs) {
      Serial.println("\nWiFi not connected yet - continuing, will keep retrying.");
      return false;
    }
    delay(500);
    Serial.print(".");
    if (millis() - attemptStart > 15000) {
      Serial.printf("\nStill not connected after 15s, WiFi.status() = %d\n",
                    WiFi.status());
      attemptStart = millis();
    }
  }
  Serial.println();
  return true;
}

static void setupCameraStreamMode() {
  Serial.println("Mode: camera live stream");

  if (!configureCamera()) {
    while (true) {
      delay(1000);
    }
  }

  connectWiFi(0);

  Serial.print("Connected! Open http://");
  Serial.print(WiFi.localIP());
  Serial.println("/ in a browser on the same network to view the stream.");

  startCameraServer();
}

// ---------------------------------------------------------------------
// APP_MODE_DORBEL - everything at once:
//   camera -> http://<ip>:81/stream   (and /capture on port 80)
//   mic    -> ws://<ip>/audio         (and the browser's talk audio back)
//   I2C    -> RING plays the chime; status + IP answered to the UNO Q
// ---------------------------------------------------------------------
static bool cameraOk = false;
static bool micOk = false;
static bool speakerOk = false;

static uint8_t dorbelStatus() {
  uint8_t flags = 0;
  if (WiFi.status() == WL_CONNECTED) flags |= STATUS_ALIVE;
  if (cameraOk) flags |= STATUS_CAMERA;
  if (micOk && speakerOk) flags |= STATUS_AUDIO;
  if (intercomTalking()) flags |= STATUS_TALK;
  return flags;
}

static void setupDorbelMode() {
  Serial.println("Mode: Dorbel V1 (camera + intercom + I2C link)");

  cameraOk = configureCamera();
  speakerOk = initSpeaker();
  micOk = initMic();
  Serial.printf("Camera %s, speaker %s, mic %s\n", cameraOk ? "OK" : "FAILED",
                speakerOk ? "OK" : "FAILED", micOk ? "OK" : "FAILED");

  // I2C first, so the doorbell chime works even while Wi-Fi is down.
  i2cLinkSetStatus(dorbelStatus());
  if (!i2cLinkBegin()) {
    Serial.println("I2C SLAVE FAILED");
  }

  connectWiFi(20000);
  startDorbelServers(micOk, speakerOk);
}

static void loopDorbelMode() {
  static uint32_t lastStatus = 0;
  static bool wasConnected = false;
  static bool wasTalking = false;

  uint8_t cmd;
  while (i2cLinkNextCommand(&cmd)) {
    switch (cmd) {
    case CMD_RING:
      Serial.println("RING COMMAND RECEIVED");
      if (speakerOk) {
        intercomRequestChime();
      }
      break;
    case CMD_PING:
    case CMD_GET_IP:
      break; // polled constantly, not worth logging
    default:
      Serial.printf("I2C command 0x%02X\n", cmd);
      break;
    }
  }

  if (millis() - lastStatus >= 250) {
    lastStatus = millis();
    bool connected = WiFi.status() == WL_CONNECTED;
    i2cLinkSetStatus(dorbelStatus());
    i2cLinkSetIp(connected ? WiFi.localIP() : IPAddress(0, 0, 0, 0));

    if (connected != wasConnected) {
      wasConnected = connected;
      if (connected) {
        String ip = WiFi.localIP().toString();
        Serial.printf("WiFi up: camera http://%s/  stream http://%s:81/stream  intercom ws://%s/audio\n",
                      ip.c_str(), ip.c_str(), ip.c_str());
      } else {
        Serial.println("WiFi lost - reconnecting");
      }
    }

    bool talking = intercomTalking();
    if (talking != wasTalking) {
      wasTalking = talking;
      Serial.println(talking ? "TALK started (browser -> speaker)" : "TALK ended");
    }
  }

  delay(10);
}

void setup() {
  Serial.begin(115200);
  // Wait briefly for the native USB CDC host so early logs aren't lost, but
  // don't hang forever when running on battery with no computer attached.
  while (!Serial && millis() < 3000) {
    delay(10);
  }
  Serial.println();

#if APP_MODE == APP_MODE_CAMERA_STREAM
  setupCameraStreamMode();
#elif APP_MODE == APP_MODE_MIC_CAPTURE
  setupMicCapture();
#elif APP_MODE == APP_MODE_SPEAKER_TEST
  setupSpeakerTest();
#elif APP_MODE == APP_MODE_MIC_LEVEL
  setupMicLevel();
#elif APP_MODE == APP_MODE_I2C_SLAVE
  setupI2cSlaveTest();
#elif APP_MODE == APP_MODE_DORBEL
  setupDorbelMode();
#else
#error "APP_MODE must be one of the APP_MODE_* values above"
#endif
}

void loop() {
#if APP_MODE == APP_MODE_SPEAKER_TEST
  loopSpeakerTest();
#elif APP_MODE == APP_MODE_MIC_LEVEL
  loopMicLevel();
#elif APP_MODE == APP_MODE_I2C_SLAVE
  loopI2cSlaveTest();
#elif APP_MODE == APP_MODE_DORBEL
  loopDorbelMode();
#else
  // Everything happens in the HTTP server's own task (camera mode), or
  // setup() already finished its one-shot recording (mic mode).
  delay(10000);
#endif
}

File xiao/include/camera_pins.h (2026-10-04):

#pragma once

// Camera pin mapping for the Seeed Studio XIAO ESP32S3 Sense
// (OV2640 sensor on the Sense expansion board)

#define PWDN_GPIO_NUM     -1
#define RESET_GPIO_NUM    -1
#define XCLK_GPIO_NUM     10
#define SIOD_GPIO_NUM     40
#define SIOC_GPIO_NUM     39

#define Y9_GPIO_NUM       48
#define Y8_GPIO_NUM       11
#define Y7_GPIO_NUM       12
#define Y6_GPIO_NUM       14
#define Y5_GPIO_NUM       16
#define Y4_GPIO_NUM       18
#define Y3_GPIO_NUM       17
#define Y2_GPIO_NUM       15
#define VSYNC_GPIO_NUM    38
#define HREF_GPIO_NUM     47
#define PCLK_GPIO_NUM     13

// Onboard white flash LED on the Sense expansion board
#define LED_GPIO_NUM      21

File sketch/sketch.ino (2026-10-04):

// Dorbel UNO Q MCU - doorbell button + RGB + I2C link to the XIAO + Bridge RPC API.
//
// Physical path:  button -> STM32 -> I2C -> XIAO -> speaker
// Software path:  STM32 -> Bridge RPC -> Python on Linux (python/main.py)
//
// RPC functions (provide_safe: they run between loop() iterations, so
// loop() must never block for long or Python's Bridge.call() stalls):
//   get_doorbell_state() -> 1 if a press happened since the last clear_event()
//   get_xiao_status()    -> last XIAO status byte, -1 if not responding
//   clear_event()        -> clears the doorbell latch, returns 1
//   get_xiao_ip()        -> XIAO IPv4 packed as a.b.c.d (a in the top byte), 0 if unknown
//
// Press the doorbell button: the UNO Q sends CMD_RING (0x02) to the XIAO,
// which plays the chime. The RGB LED shows system state:
//   GREEN = idle, XIAO answering
//   RED   = ring just sent
//   BLUE  = XIAO not answering on I2C (check wiring / XIAO firmware)
//
// Pins: D2 button (to GND), D3/D5/D6 RGB, A4/A5 I2C (Wire2) to XIAO D4/D5.

#include <Arduino_RouterBridge.h>
#include <Wire.h>

#define DORBEL_WIRE Wire2
#define XIAO_ADDR   0x08
#define CMD_RING    0x02
#define CMD_GET_IP  0x05

#define BUTTON_PIN 2
#define RED_PIN    3
#define GREEN_PIN  5
#define BLUE_PIN   6

#define LED_COMMON_ANODE 0

const unsigned long DEBOUNCE_MS     = 30;
const unsigned long RING_LOCKOUT_MS = 1500; // ignore re-presses while the chime plays
const unsigned long RING_LED_MS     = 1000;
const unsigned long STATUS_POLL_MS  = 1000;
const unsigned long IP_POLL_MS      = 5000;

int xiaoStatus = -1; // last status byte, -1 = no response
int xiaoIp = 0;      // packed IPv4 from the XIAO, 0 = unknown
unsigned long lastRingAt = 0;
bool ringShown = false;
bool doorbellEvent = false; // latched until Python calls clear_event()

int get_doorbell_state() {
  return doorbellEvent ? 1 : 0;
}

int get_xiao_status() {
  return xiaoStatus;
}

int clear_event() {
  doorbellEvent = false;
  return 1;
}

int get_xiao_ip() {
  return xiaoIp;
}

void setRGB(bool r, bool g, bool b) {
  digitalWrite(RED_PIN,   r != LED_COMMON_ANODE);
  digitalWrite(GREEN_PIN, g != LED_COMMON_ANODE);
  digitalWrite(BLUE_PIN,  b != LED_COMMON_ANODE);
}

bool sendCommand(uint8_t cmd) {
  DORBEL_WIRE.beginTransmission(XIAO_ADDR);
  DORBEL_WIRE.write(cmd);
  return DORBEL_WIRE.endTransmission() == 0;
}

int readStatus() {
  if (DORBEL_WIRE.requestFrom(XIAO_ADDR, 1) == 1) {
    return DORBEL_WIRE.read();
  }
  return -1;
}

// The XIAO answers the read right after CMD_GET_IP with 4 address bytes.
int readIp() {
  if (!sendCommand(CMD_GET_IP)) {
    return 0;
  }
  if (DORBEL_WIRE.requestFrom(XIAO_ADDR, 4) != 4) {
    return 0;
  }
  uint32_t ip = 0;
  for (int i = 0; i < 4; i++) {
    ip = (ip << 8) | (uint8_t)DORBEL_WIRE.read();
  }
  return (int)ip;
}

// True once per press: falling edge that has stayed LOW for DEBOUNCE_MS.
bool buttonPressedEdge() {
  static bool stable = HIGH;
  static bool lastRaw = HIGH;
  static unsigned long changedAt = 0;

  bool raw = digitalRead(BUTTON_PIN);
  if (raw != lastRaw) {
    lastRaw = raw;
    changedAt = millis();
  }
  if (raw != stable && millis() - changedAt >= DEBOUNCE_MS) {
    stable = raw;
    return stable == LOW;
  }
  return false;
}

void updateLed() {
  if (ringShown && millis() - lastRingAt < RING_LED_MS) {
    setRGB(true, false, false);
  } else if (xiaoStatus < 0) {
    setRGB(false, false, true);
  } else {
    setRGB(false, true, false);
  }
}

void setup() {
  Bridge.begin();
  Bridge.provide_safe("get_doorbell_state", get_doorbell_state);
  Bridge.provide_safe("get_xiao_status", get_xiao_status);
  Bridge.provide_safe("clear_event", clear_event);
  Bridge.provide_safe("get_xiao_ip", get_xiao_ip);

  Monitor.begin();
  delay(1500); // Monitor drops output sent right after begin()

  pinMode(BUTTON_PIN, INPUT_PULLUP);
  pinMode(RED_PIN, OUTPUT);
  pinMode(GREEN_PIN, OUTPUT);
  pinMode(BLUE_PIN, OUTPUT);

  DORBEL_WIRE.begin();
  DORBEL_WIRE.setClock(100000);

  xiaoStatus = readStatus();
  Monitor.print("Doorbell ready, XIAO ");
  Monitor.println(xiaoStatus < 0 ? "NOT responding" : "OK");
  updateLed();
}

void loop() {
  static unsigned long lastPoll = 0;
  static unsigned long lastIpPoll = 0;

  if (buttonPressedEdge()) {
    if (ringShown && millis() - lastRingAt < RING_LOCKOUT_MS) {
      Monitor.println("Button pressed (ignored, chime still playing)");
    } else {
      bool ok = sendCommand(CMD_RING);
      lastRingAt = millis();
      ringShown = true;
      doorbellEvent = true;
      Monitor.print("DOORBELL PRESSED -> RING ");
      Monitor.println(ok ? "sent" : "FAILED (no ACK)");
    }
  }

  if (millis() - lastPoll >= STATUS_POLL_MS) {
    lastPoll = millis();
    int s = readStatus();
    if ((s < 0) != (xiaoStatus < 0)) {
      Monitor.println(s < 0 ? "XIAO stopped responding" : "XIAO back online");
    }
    xiaoStatus = s;
  }

  if (millis() - lastIpPoll >= IP_POLL_MS) {
    lastIpPoll = millis();
    xiaoIp = xiaoStatus < 0 ? 0 : readIp();
  }

  updateLed();
  delay(5);
}
